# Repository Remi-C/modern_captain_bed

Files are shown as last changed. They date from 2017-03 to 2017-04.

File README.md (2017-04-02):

# Modern captain bed #

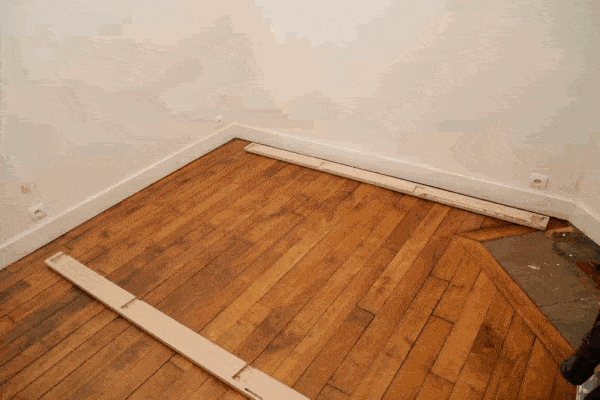
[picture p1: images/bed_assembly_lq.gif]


## Presentation ##

This is a re-design of captain bed in a modern fashion.

The main design ideas :
 - a nice wooden bed inspired by nautical captain bed
 - massive amount of storage (about 2 m3!)
 - Massive wood, traditionnal joinery for strength and durability
 - fully dismountable into small pieces (one person carry)
 - Can be build with reasonnably common tools/

warning : the original design documents are in french, I translated the essential parts

Here is a detailed presentation of this moder captain bed project.

[Introductory presentation to the modern captain bed project](./presentation/modern_captain_bed_overall_presentation.pdf) ([French version](./presentation/modern_captain_bed_overall_presentation_LQ_fr.pdf))

## 3D model
A conceptual 3D model, simplified (no joinery, no handles, simplified textures, etc.)

**click on 3D model to change view**
<div class="sketchfab-embed-wrapper"><iframe width="800" height="600" src="https://sketchfab.com/models/c7bc11224e4042eab323be94998c2b65/embed" frameborder="0" allowvr allowfullscreen mozallowfullscreen="true" webkitallowfullscreen="true" onmousewheel=""></iframe>

<p style="font-size: 13px; font-weight: normal; margin: 5px; color: #4A4A4A;">
    <a href="https://sketchfab.com/models/c7bc11224e4042eab323be94998c2b65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" target="_blank" style="font-weight: bold; color: #1CAAD9;">Modern Captain Bed</a>
    by <a href="https://sketchfab.com/RCura?utm_medium=embed&utm_source=website&utm_campain=share-popup" target="_blank" style="font-weight: bold; color: #1CAAD9;">RCura</a>
    on <a href="https://sketchfab.com?utm_medium=embed&utm_source=website&utm_campain=share-popup" target="_blank" style="font-weight: bold; color: #1CAAD9;">Sketchfab</a>
</p>
</div>
 
[Go to `3D_model` for 3D model !](./3D_model/modern_captain_bed.dae)

## Design
The design took several months as the project is mechanically complex to solve with traditionnal joinery wihtout loosing storage space.
Moreover, the dissassembled bed has to be easy to move and store.

**Clik on image to see other images**
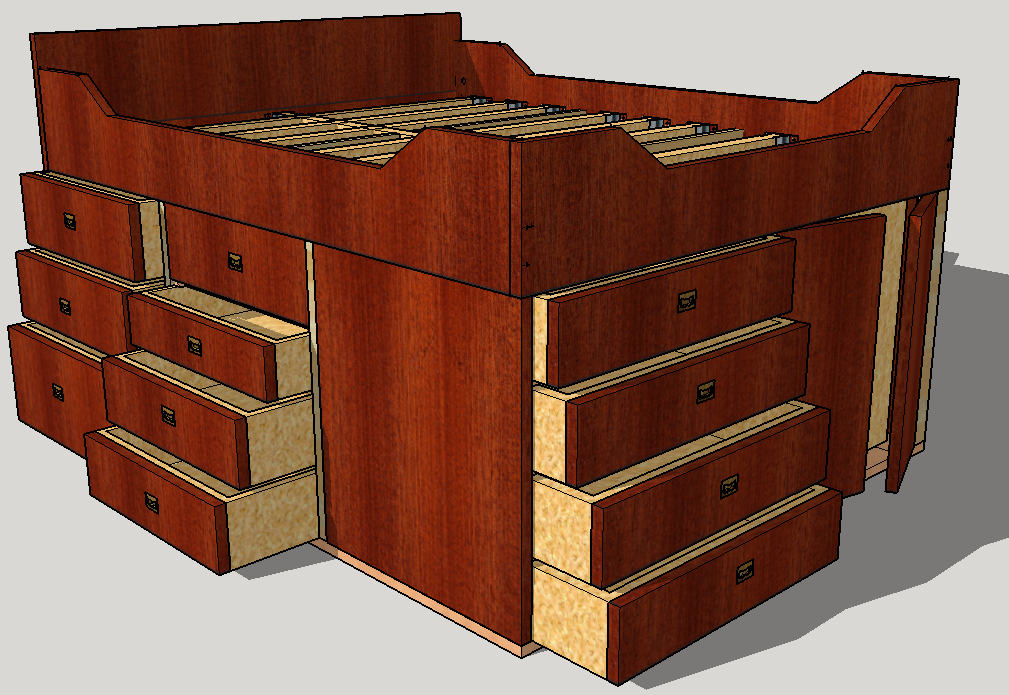
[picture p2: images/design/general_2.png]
Disassembled bed

The gallery of pictures for design contains many pictures about the design step.

The most recent version of the project design dimension are :

**Clik on image to see other images**
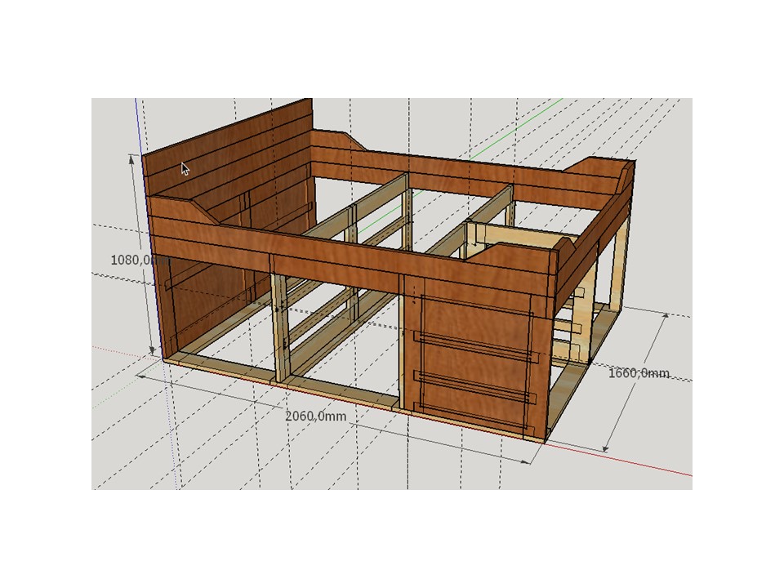
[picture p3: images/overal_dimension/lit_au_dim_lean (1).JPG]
overal dimension


## Building
The project was built in 6 months using evenings and week ends.
Overall, the project can be completed with common woodworking tools.
Mixing power tool and hand tool is also possible.

**clik on image to see other images**
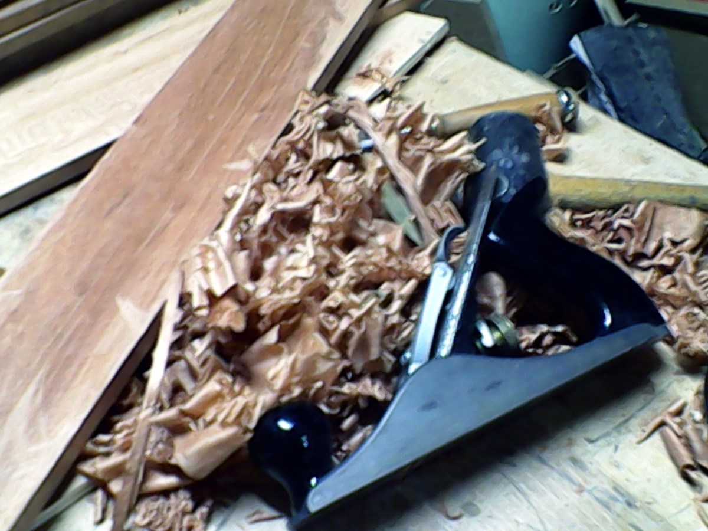
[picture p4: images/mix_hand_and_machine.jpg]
hand tool
 
The gallery contains some pictures of the build process.

### build-book
Beside the 3D model, the [build book](./building/build_book/modern_captain_bed_build_book.pdf) contains illustrated parts, nomenclature and measurements.

**clik on image to see other images**
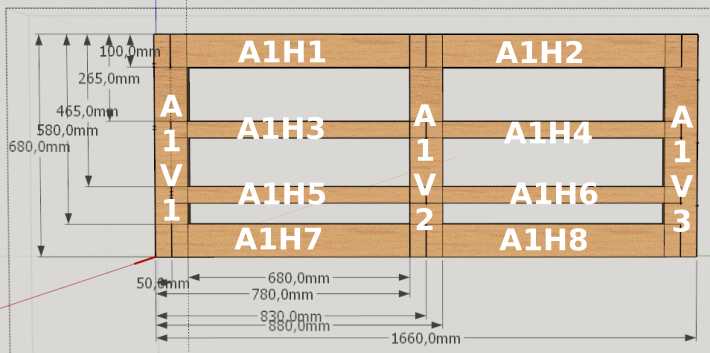
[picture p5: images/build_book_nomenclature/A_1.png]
gallery
.

### template
Some joins are duplicated heavily, which make them lenghty to draw on wood.
We propose numerical templates to be used with router or  similar tools.
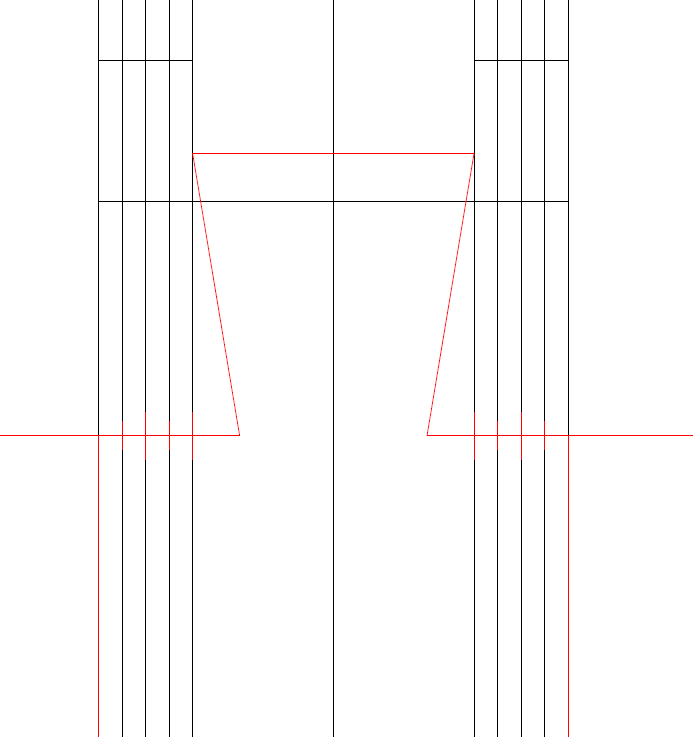
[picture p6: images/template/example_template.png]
numerical templates


## Assembly##
The main design advantage of this bed is the traditionnal joinery that allows full assembly / disassembly.
### Pictures of assembly
As shown in the assembly galleries, assembling bed is straightforward.

**clik on image to see other images**
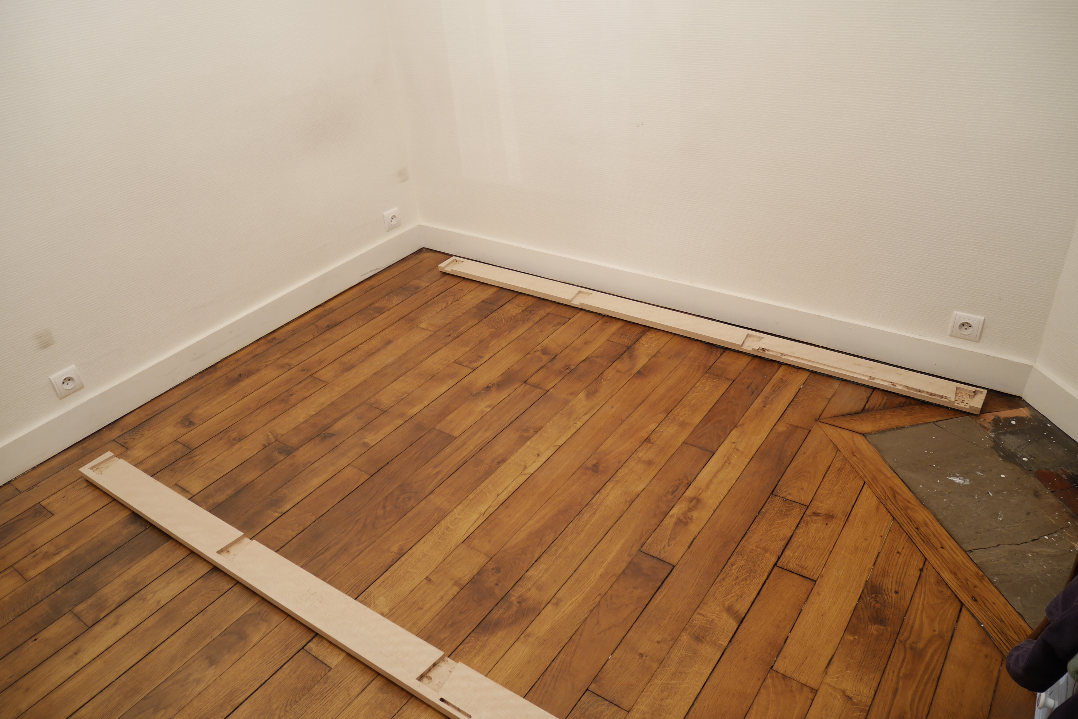
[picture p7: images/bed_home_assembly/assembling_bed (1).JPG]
assembling bed at home


**clik on image to see other images**
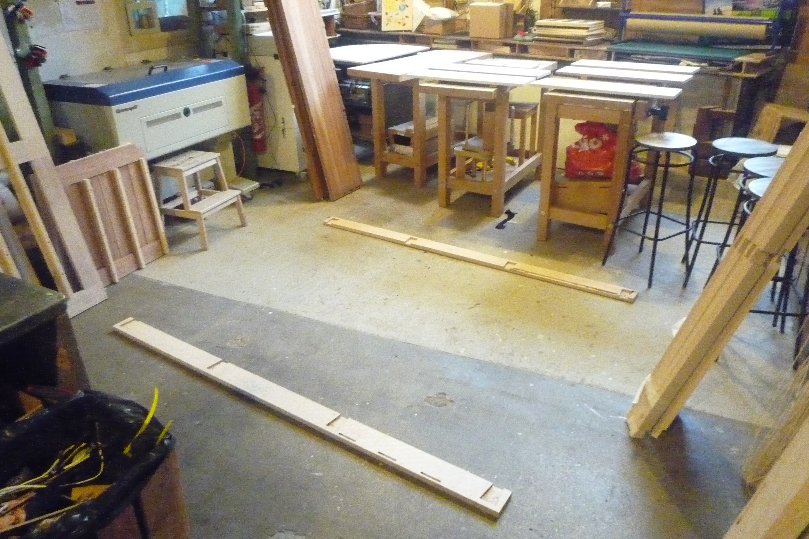
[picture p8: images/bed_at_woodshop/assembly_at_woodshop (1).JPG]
assembling bed at woodshop


### Moving the bed
The bed can be dissassembled into small parts, such that no part is longuer than 2 meters, larger than 40 cm, and of more than 10 cm of thickness.
Furthermore, each part is light enough to be carreid  by one person.
Overall, the bed dissassembled easily fit into a 2m x 1m x 0.3 m space. 
**clik on image to see other images**
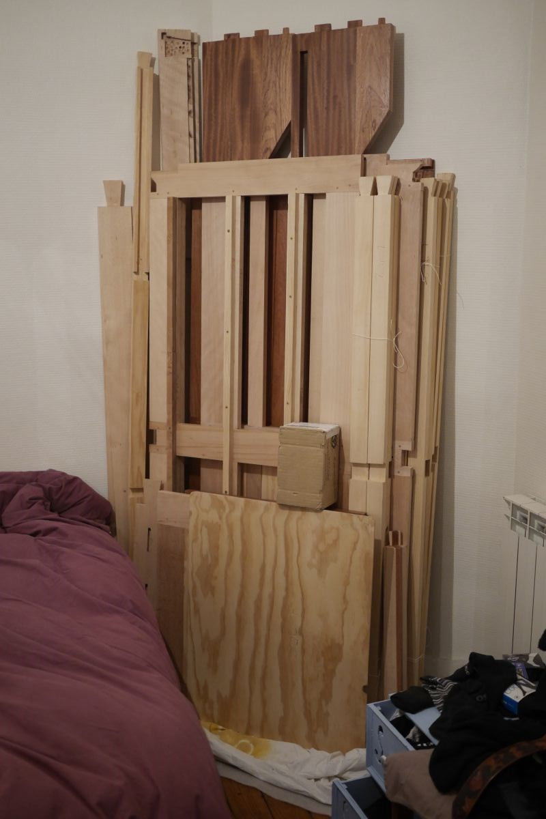
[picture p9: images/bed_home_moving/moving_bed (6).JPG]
Moving the bed


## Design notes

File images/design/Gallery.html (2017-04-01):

# Gallery

Click on picture to enlarge.





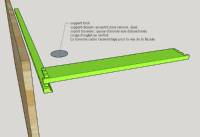
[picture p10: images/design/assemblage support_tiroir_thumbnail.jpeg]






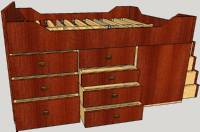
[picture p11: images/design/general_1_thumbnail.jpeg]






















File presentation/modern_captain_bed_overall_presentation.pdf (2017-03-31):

# A modern captain bed

# Rémi Cura, 2015

# Introduction

# - Main design ideas

# – A bed with massive storage space – Tough – Doable, can be assembled/disassembled – Beautifull materials for a nautic style esthetic

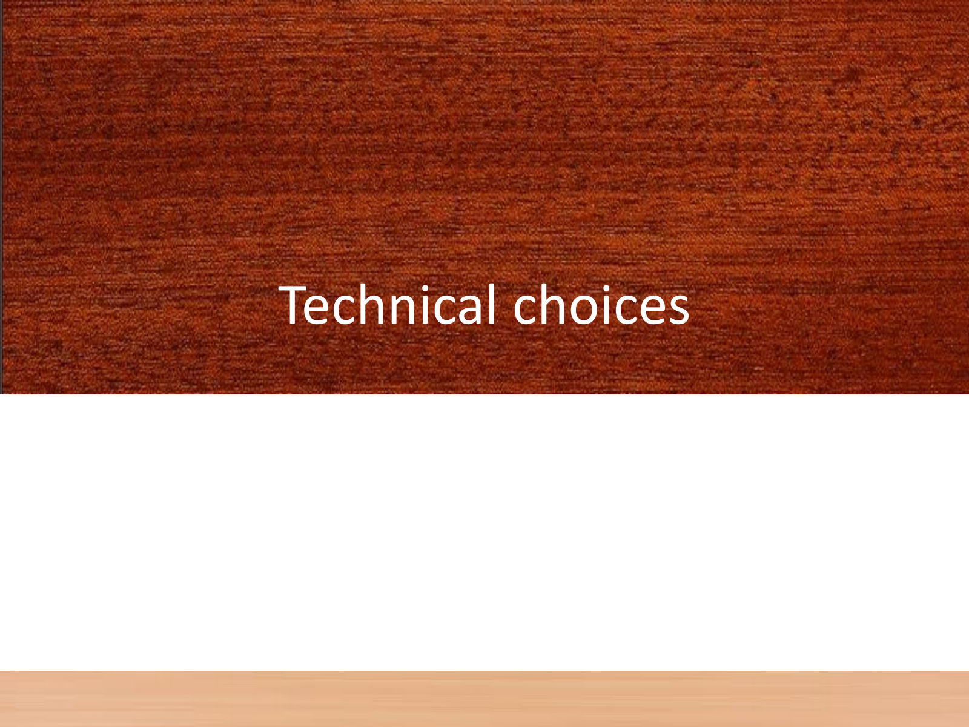
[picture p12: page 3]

# Technical choices

# Esthetic choices

# - Main inspiration is actual captain bed, in particular for:

## – Its compactness (nothing protruding) – Its warm colors (mahogany+ brass) – Its toughness – Its simplicity (no curves)

# - We adapt it to modern constraints

## – Maximal storing space – A few sharp edges accepted

# - Height

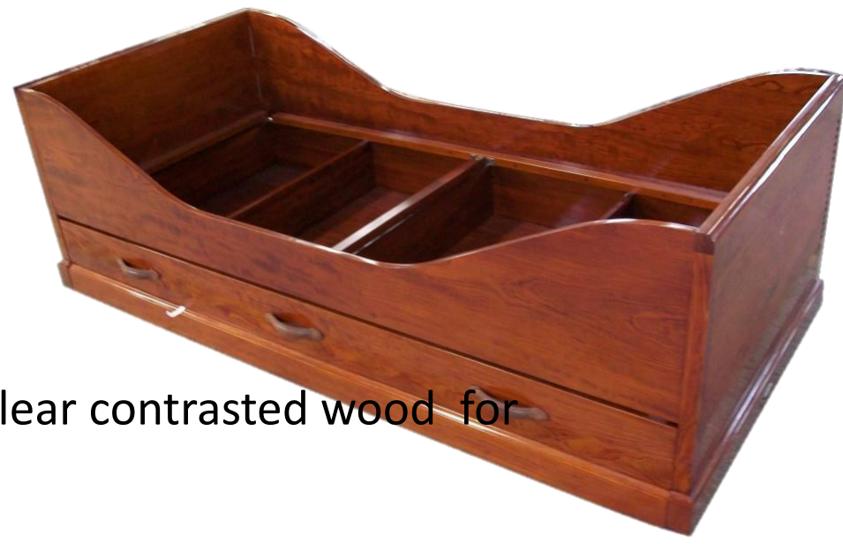
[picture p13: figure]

## – To limit the height impression, we use clear contrasted wood for vertical parts

# Technical choices

# - Passing through drawers (full bed width) - Main dimensions

## – Mattress is 1600*2000mm – Bed frame is at about height 850 mm – Thickness for main parts (belt) :30mm – Thickness structural part(frame) : 20 mm – Thickness secondary element (drawer bottom): 10mm

# - Joinery choices

## – removable – Mecanically sound – Easy to construct – Use metal parts only when absolutely necessary

# Technical choices

# - About materials

## – Visible wood:

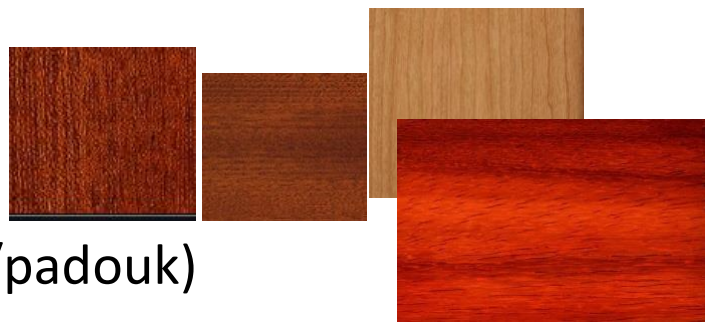
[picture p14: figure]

## - Hard, dark/red colour(acajou/sapelli/merisier/padouk)

## – Structure (cloison):

## - Hard, light colour: hêtre/chataignier/frêne

## – Drawer Not visible:

## - rigid cheap :plywood/latté

## – Mattress floor:

## - Light cheap(pin/epicea…)

# - hardware

## – Visible : brass – Invisible : brass/ stainless/ steel

# Technical choices

# - About sketchup 3D model

# – More a detailed concept – Joinery is sometime showed, but not always ( sketchup is buggy) – Some stuff are hand placed and are not precise

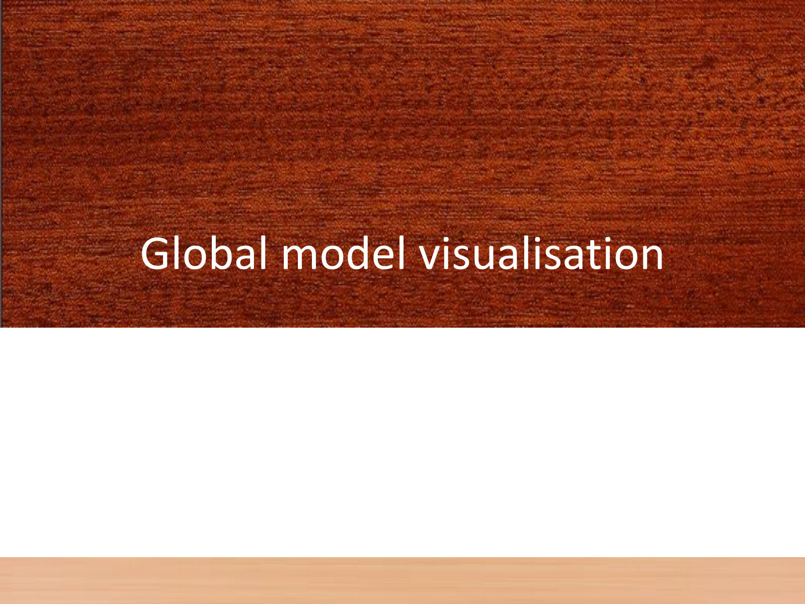
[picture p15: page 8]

# Global model visualisation

# Global visu

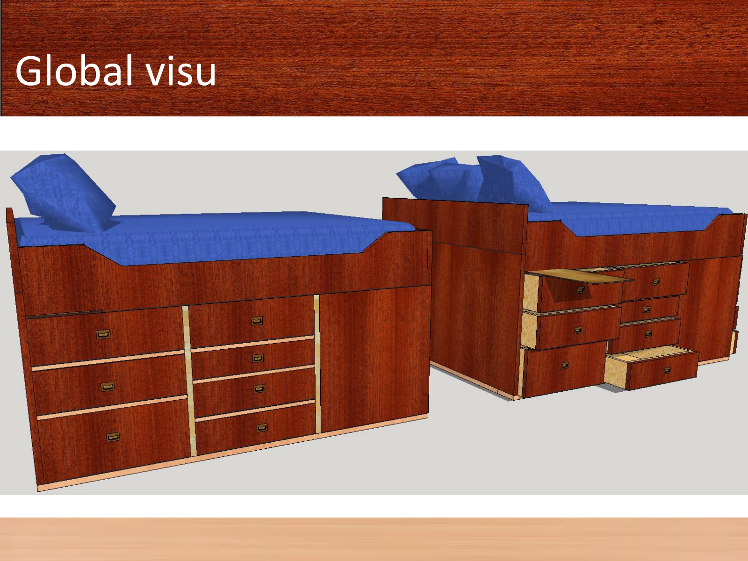
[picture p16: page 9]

# Global visu

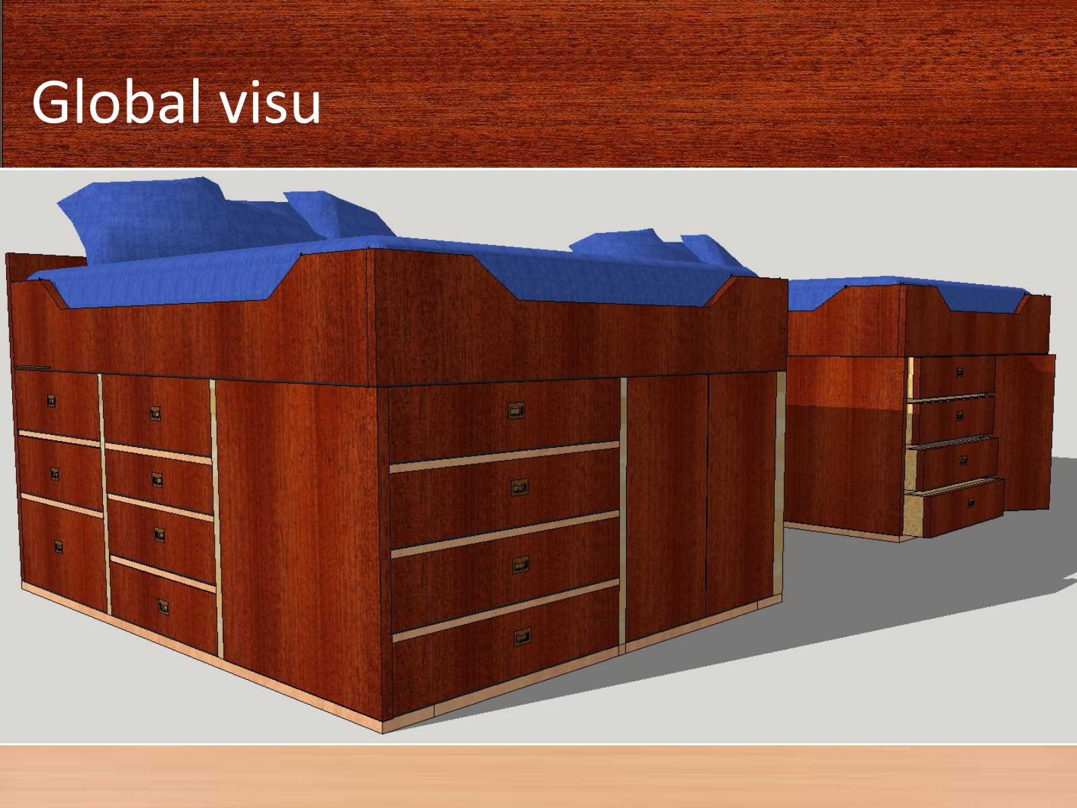
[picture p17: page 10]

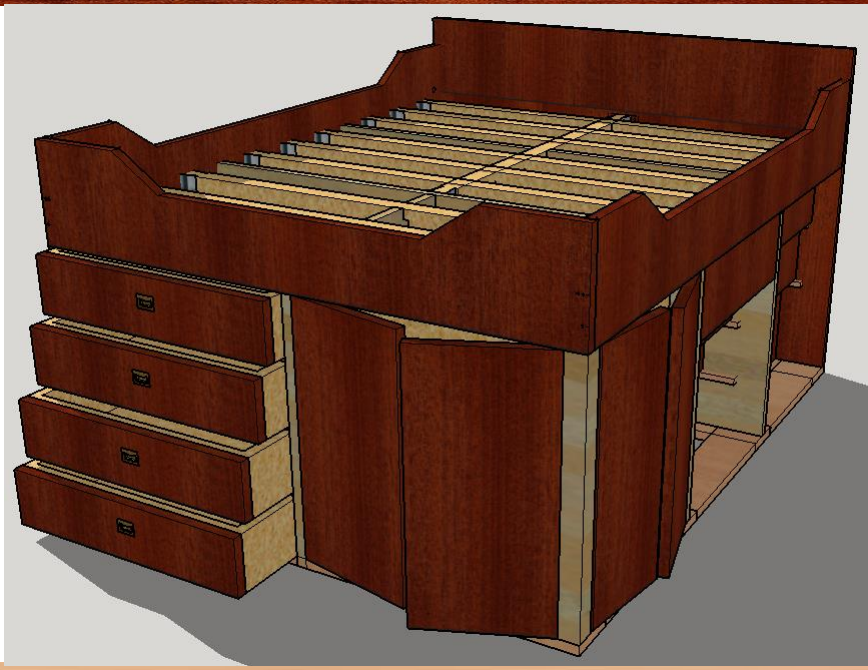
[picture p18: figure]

(all drawers and doors have handle)
(behing door, either a box, shelf, or nothing)

# Global visu

(all drawers and doors have handle)
(this illustration misses some

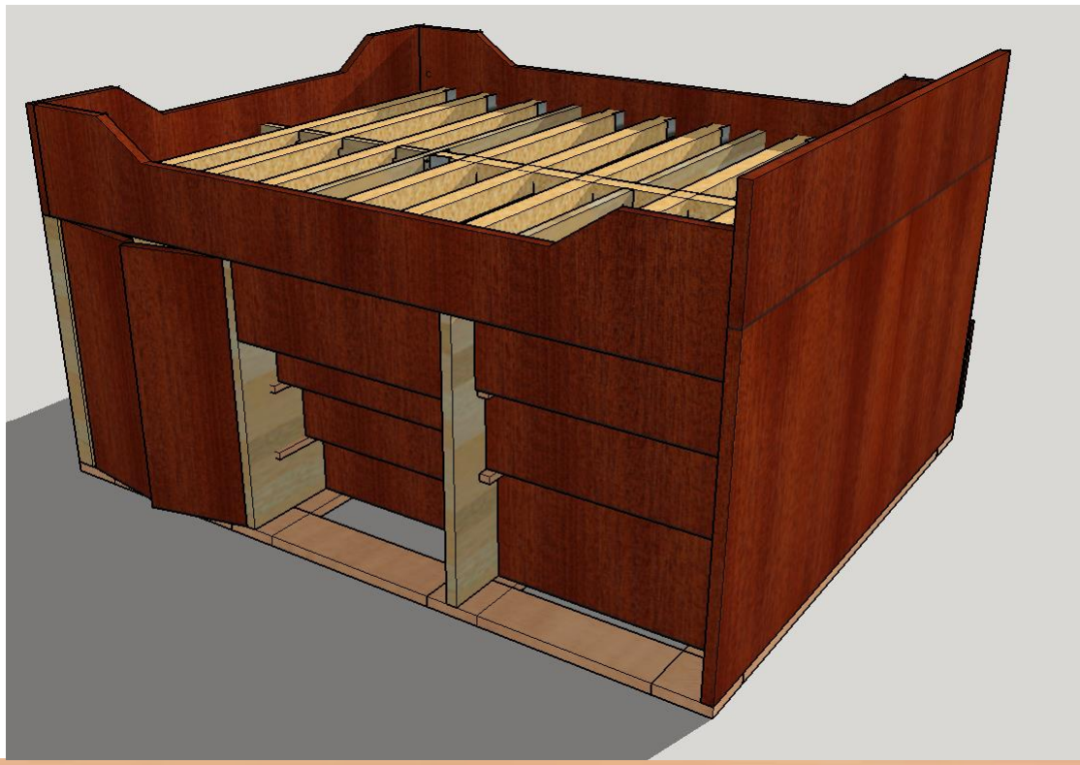
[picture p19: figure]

part of the drawers supports)

# Global visu

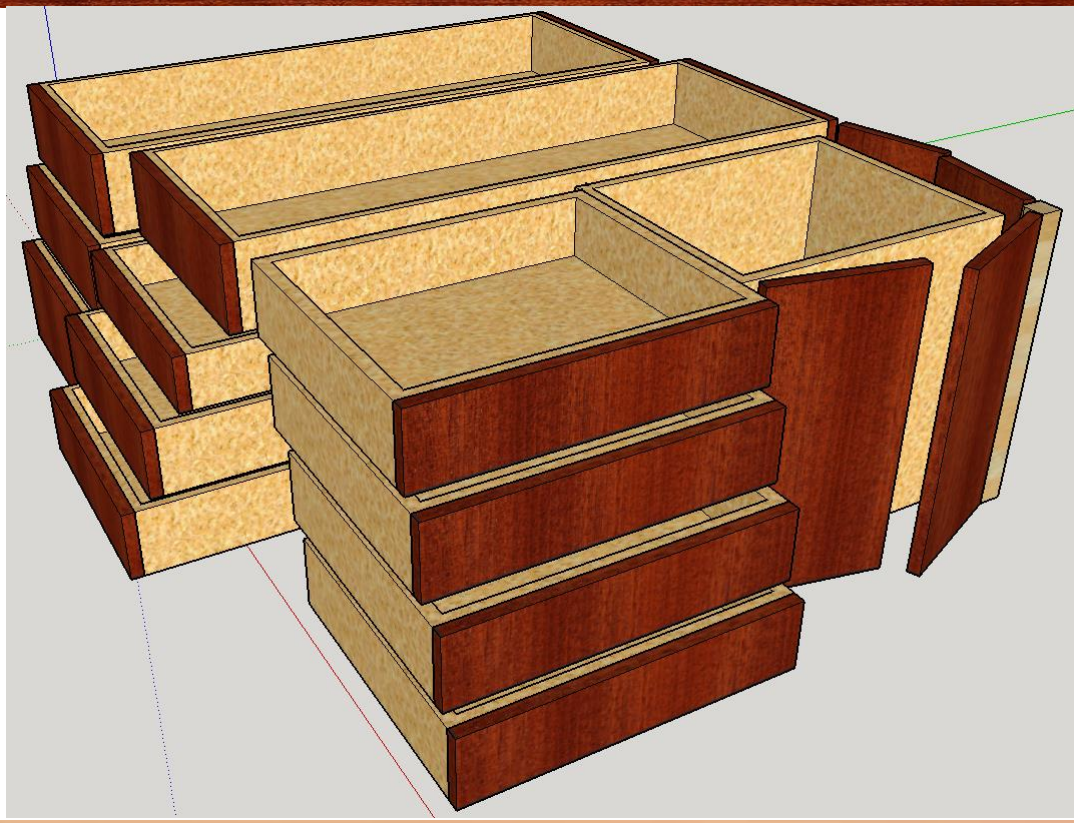
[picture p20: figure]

(tous les tiroirs et portes devraient avoir une poignée) (les assemblages des tiroirs ne sont pas montrés ici)

Note : les doubles portes
battantes permettent
d’accéder au même coffre.
Avec les tiroirs traversant, cela permet d’utiliser le
stockage même quand le lit est le long d’un murs sur un des côtés.
Les doubles battants
permettent un espace au
pied du lit plus réduit, et sont meilleurs d’un point de vue macanique (800mm de
portée un peu long pour un simple battant)

# Global visu

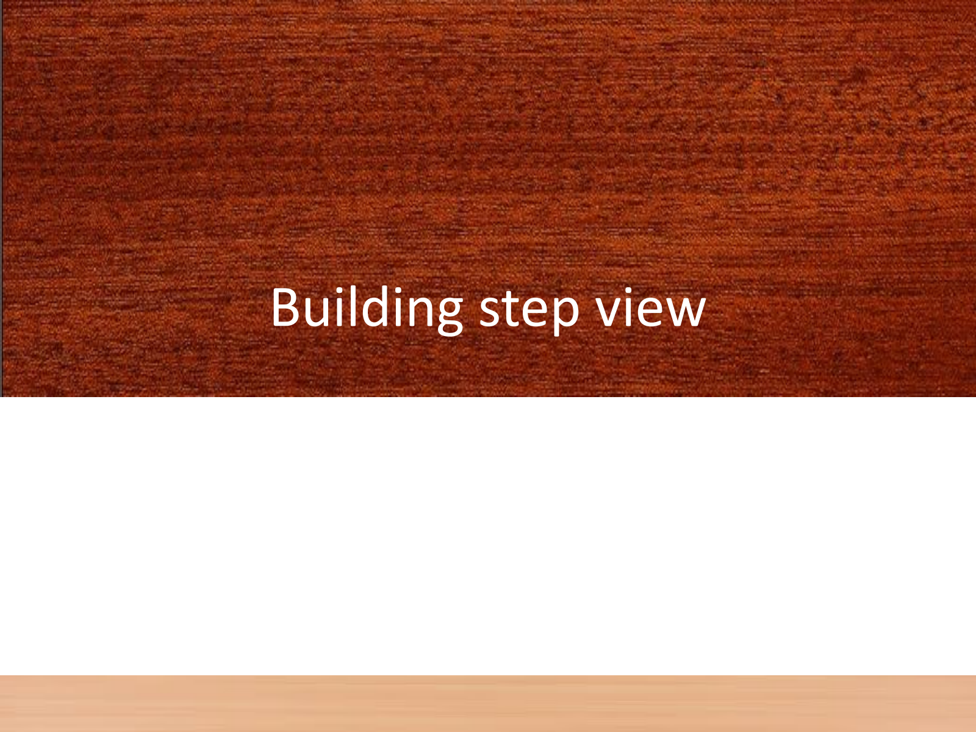
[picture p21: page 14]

# Building step view

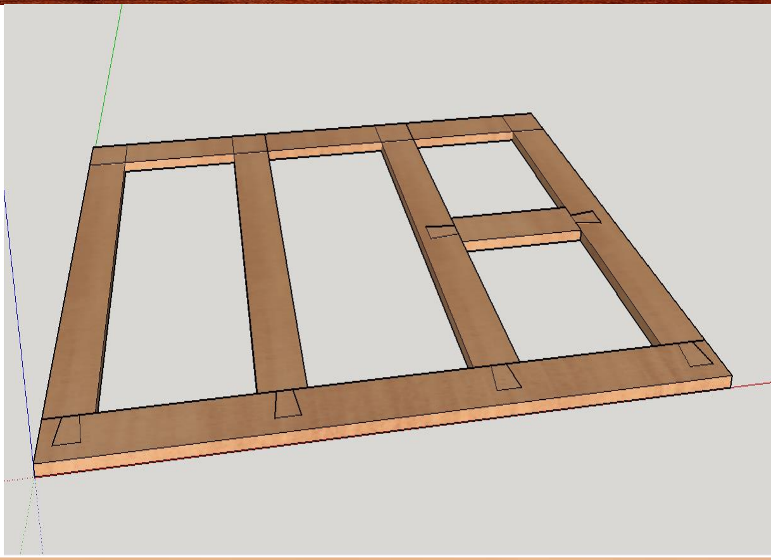
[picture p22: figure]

(Not all joins are drawn)

# Socle

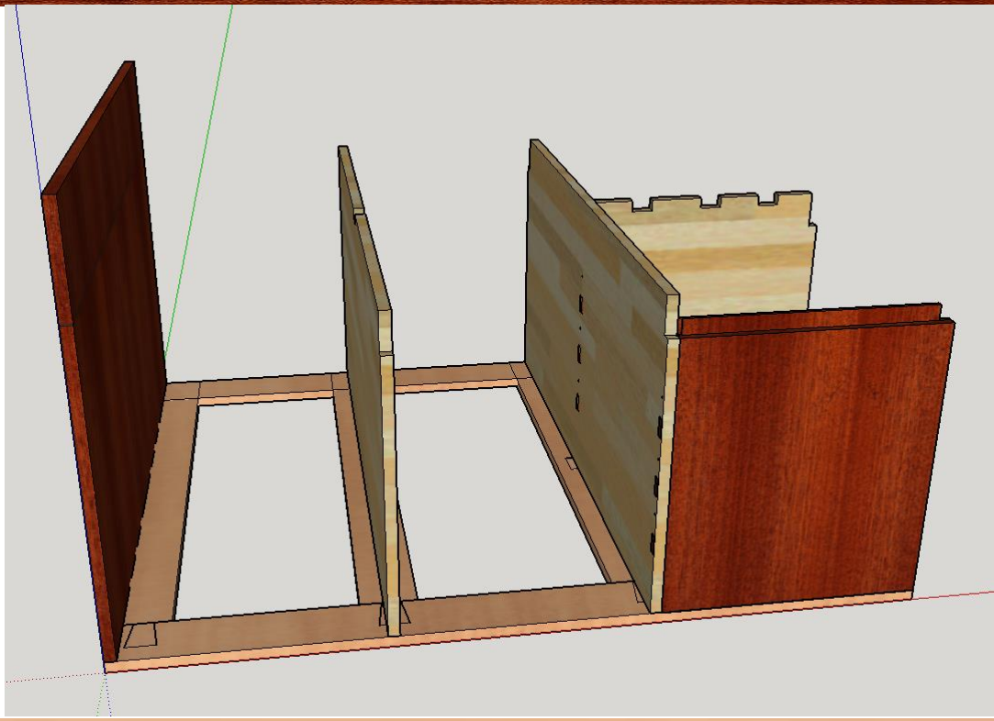
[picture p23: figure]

(Not all joins are drawn)

# + cloisons

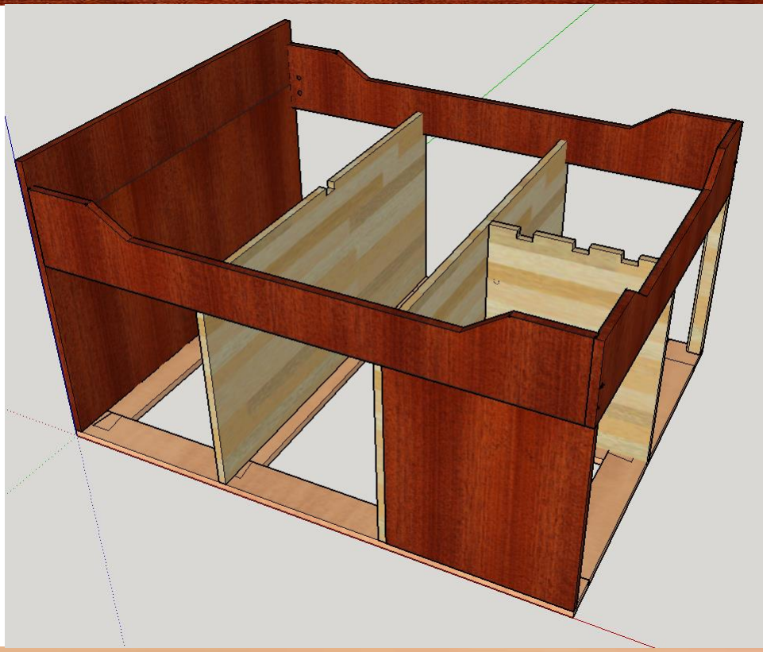
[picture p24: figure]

(Not all joins are drawn)

# + traverses

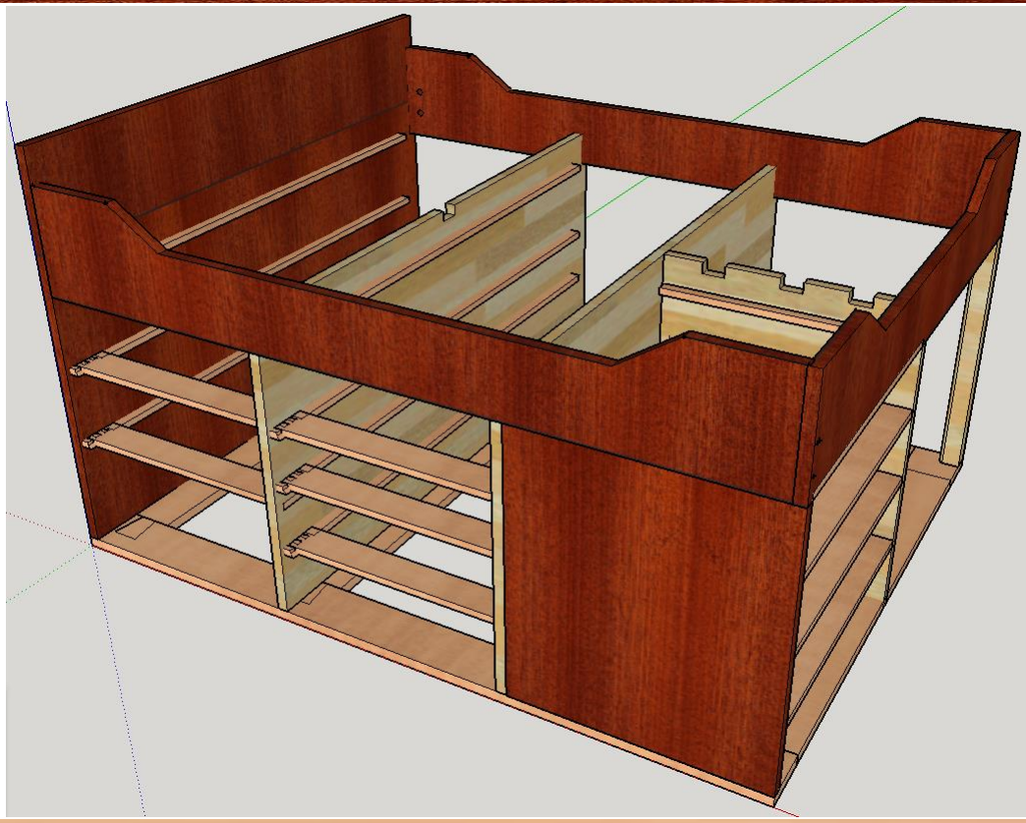
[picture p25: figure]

(Not all joins are drawn)

# + supports tiroirs

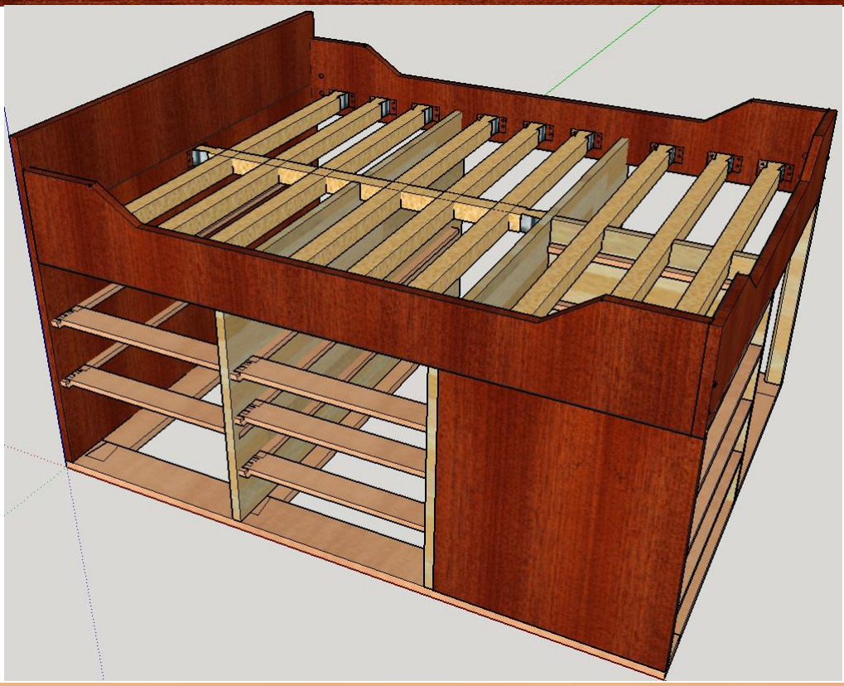
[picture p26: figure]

(Not all joins are drawn)

# + sommier

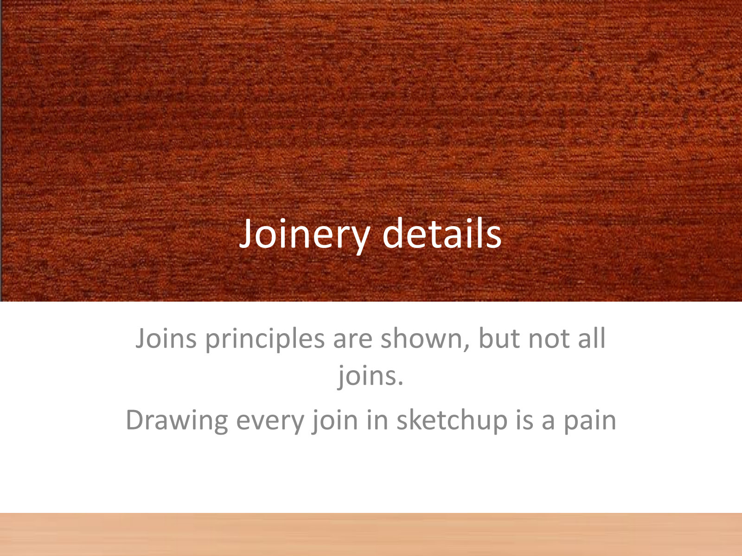
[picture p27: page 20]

# Joinery details

# Joins principles are shown, but not all

joins.

# Drawing every join in sketchup is a pain

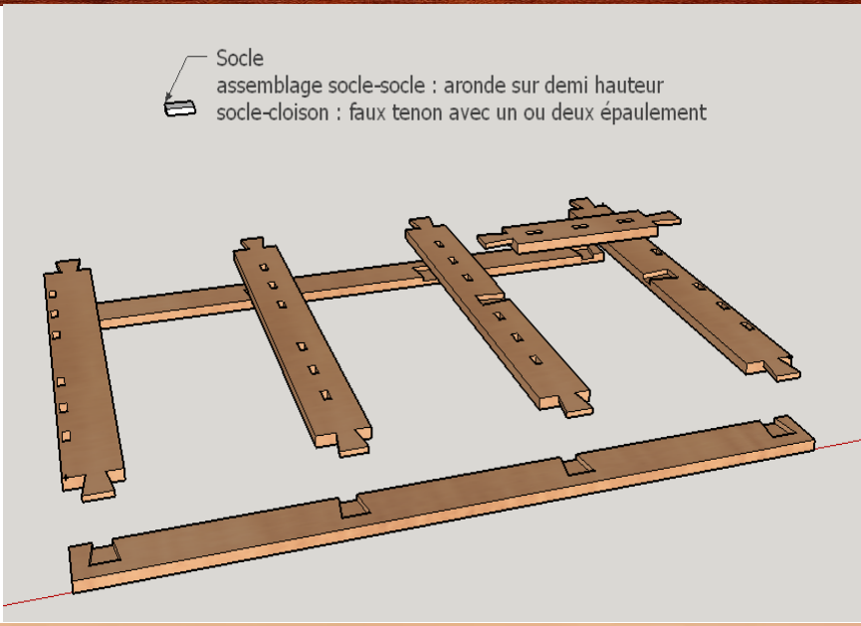
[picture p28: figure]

(Not all joins are drawn)
Dovetails on half width allow easy dissambly, are super
rigid, and will handle
dimension variations

Tenon are simple and save
wood

# + socle

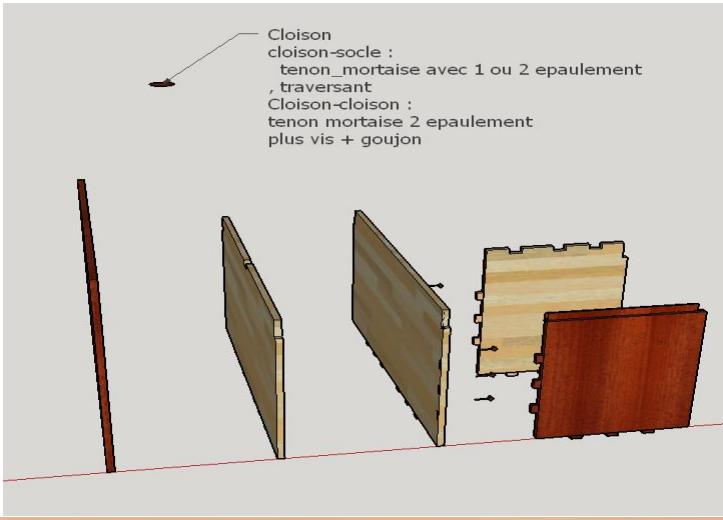
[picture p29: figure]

(Not all joins are drawn)
We use hardware to join
panneaux. This allow to
control tightness and is still easily removable.

# + cloisons

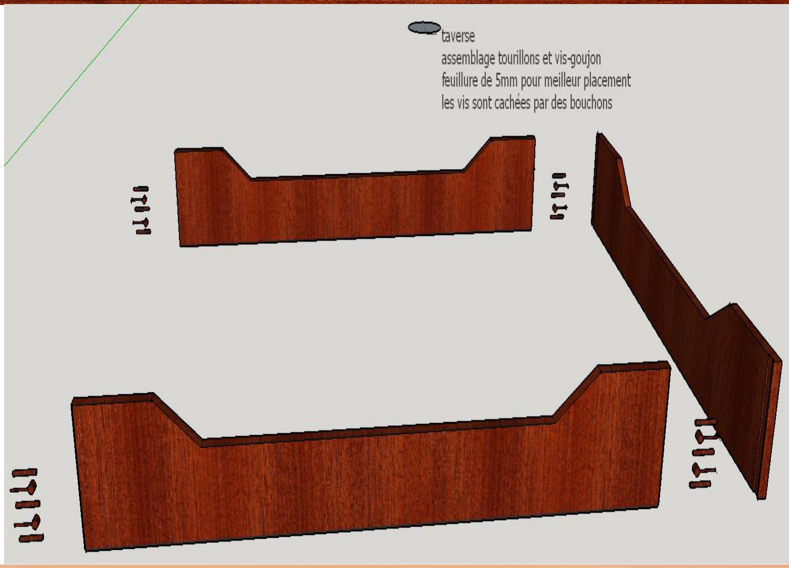
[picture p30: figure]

(Not all joins are drawn)

Il ne seemble pas y avoir bcp de possiblités pour ces
assemblages car la largeur des planches (30mm) est
insuffisante pour bcp
d’assemblages plus solides. Ces jonctions doivent être extremement fortes.
On utilise donc des vis
traversantes cachées par des bouchons de bois pour
l’esthétique

# + ceinture

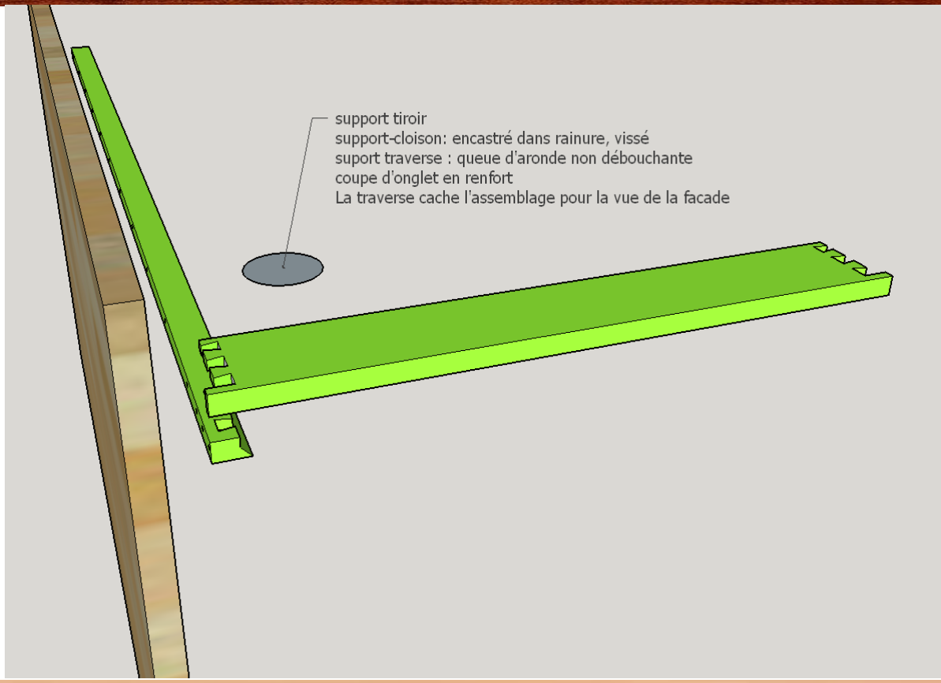
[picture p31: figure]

(tous les assemblages ne
sont pas représentés)

Ces assemblages devrait être faisable avec une défonceuse avec meche droite assez fine et gabarit.
C’est essentiel car il y en a bcp.
L’onglet en basde
l’assemblage permet de bien repartir la charge du tiroir Les arondes permettent de
transmettres les
mouvements des cloisons à
toute la structure

# + support tiroir

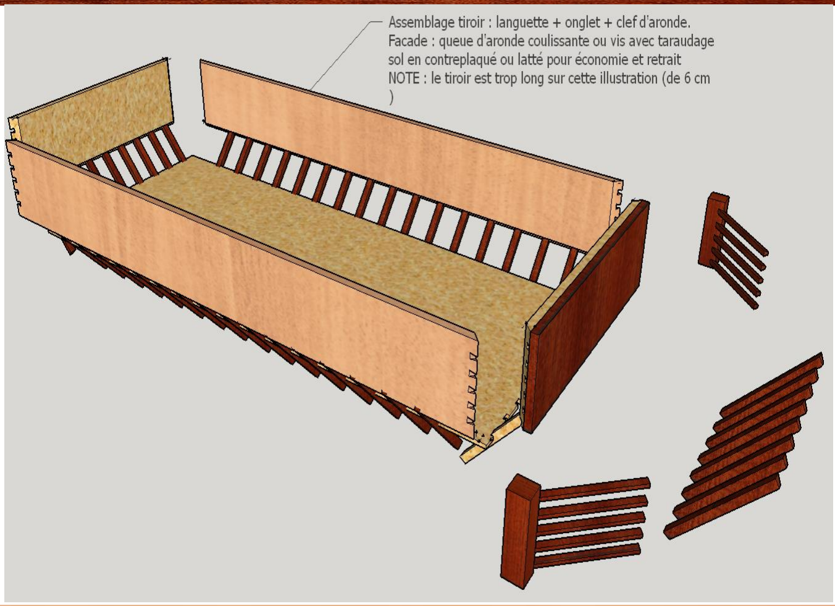
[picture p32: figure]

- Les clefs d’arondes sont représentées non coupées
- L’assemblage par clef
d’aronde semble etre un
bon compromis d’usinage,
puisqu’on fait d’abord un
assemblage « facile» avec
feuillures, puis on colle le tiroir.
- On défonce les clefs sur le tiroir déjà assemblé, ce qui évite l’utilisation d’un
gabarit à queue d’aronde.
- Mécaniquement les clefs
bloque traction et
déformation par le poids
- C’est esthétique si les clefs sont faites dans un autre
bois
- Elles ne sont pas
débouchantes sur la facade
- Le système de fixation
facade tiroir est soit vis taraudé, soit aronde
coulissante verticalement, ce qui ferait perdre bcp de bois

# + tiroir

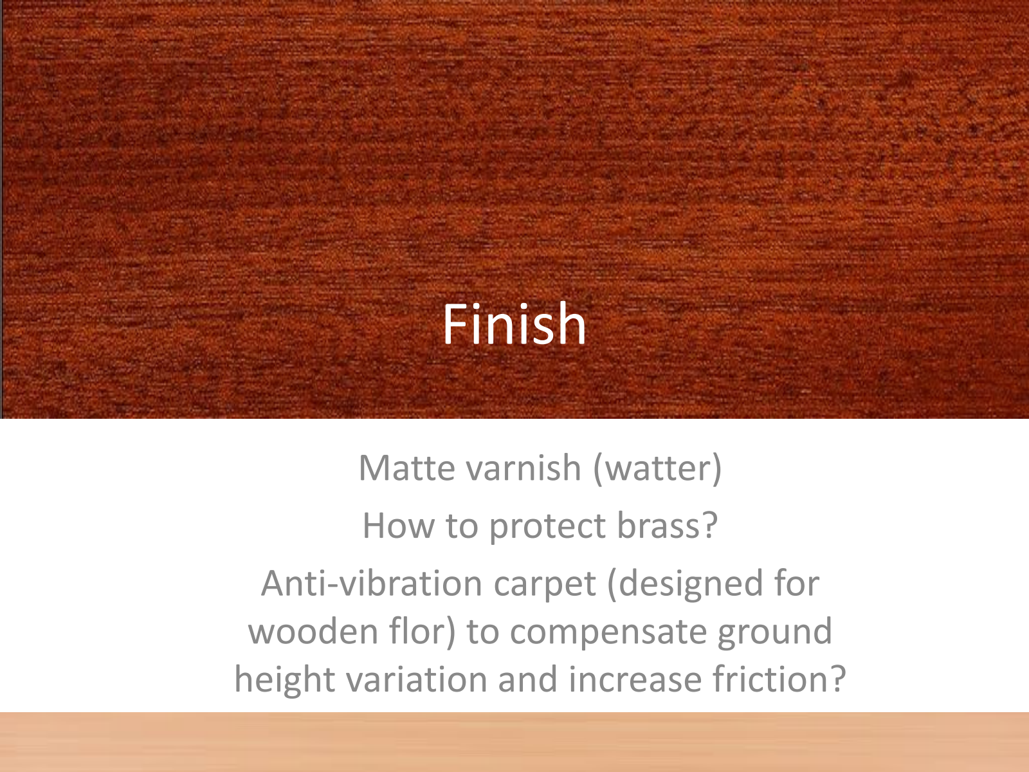
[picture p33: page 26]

# Finish

# Matte varnish (watter) How to protect brass? Anti-vibration carpet (designed for wooden flor) to compensate ground height variation and increase friction?


# Optionnal


Bonus:
A brass shelf.
Can be pushed inside
Can be used only fully in or fully out
Allow for a bedside table
without blocking drawers
opening
Joinery : groove; at the end, centering -45° + 45° profile.

Shelf surface is itched with acid, sculpted, or machined with cnc. Could also be
sculpted leather.
Idea for patter : nautical map from 19th century, vintage moon map.

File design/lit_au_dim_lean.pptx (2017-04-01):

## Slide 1


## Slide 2


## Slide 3





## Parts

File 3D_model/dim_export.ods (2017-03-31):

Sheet: Feuille1_3
Components
Part # | Sub-Assembly | Description | Length(L) | Width(W) | Thickness(T) | Cubic m | Material
C-001-01 | SOC | SOC_GD_2 | 1660,0mm | 100,0mm | 24,0mm | 0 | massif_hetre
C-002-01 | SOC | SOC_GD_4 | 1660,0mm | 100,0mm | 24,0mm | 0 | massif_hetre
C-003-01 | SOC | SOC_TP_1 | 2060,0mm | 100,0mm | 24,0mm | 0 | massif_hetre
C-004-01 | SOC | SOC_GD_3 | 1660,0mm | 100,0mm | 24,0mm | 0 | massif_hetre
C-005-01 | SOC | SOC_P | 710,0mm | 580,0mm | 10,0mm | 0 | contreplaquÃ©_pin
C-006-01 | SOC | SOC_TP_3 | 2060,0mm | 100,0mm | 24,0mm | 0 | massif_hetre
C-007-01 | SOC | SOC_TP_2 | 750,0mm | 100,0mm | 24,0mm | 0 | massif_hetre
C-008-01 | SOC | SOC_GD_1 | 1660,0mm | 100,0mm | 24,0mm | 0 | massif_hetre
C-009-01 | L_T | L_T_4 | 1600,0mm | 50,0mm | 30,0mm | 0 | tasseau_pin
C-010-01 | L_T | L_T_3 | 1600,0mm | 50,0mm | 30,0mm | 0 | tasseau_pin
C-011-01 | L_T | L_T_2 | 1600,0mm | 50,0mm | 30,0mm | 0 | tasseau_pin
C-012-01 | L_T | L_T_1 | 1600,0mm | 50,0mm | 30,0mm | 0 | tasseau_pin
C-013-01 | L_M | L_M_4 | 1600,0mm | 50,0mm | 30,0mm | 0 | tasseau_pin
C-014-01 | L_M | L_M_3 | 1600,0mm | 50,0mm | 30,0mm | 0 | tasseau_pin
C-015-01 | L_M | L_M_2 | 1600,0mm | 50,0mm | 30,0mm | 0 | tasseau_pin
C-016-01 | L_M | L_M_1 | 1600,0mm | 50,0mm | 30,0mm | 0 | tasseau_pin
C-017-01 | L_P | L_P_4 | 1600,0mm | 50,0mm | 30,0mm | 0 | tasseau_pin
C-018-01 | L_P | L_P_3 | 1600,0mm | 50,0mm | 30,0mm | 0 | tasseau_pin
C-019-01 | L_P | L_P_2 | 1600,0mm | 50,0mm | 30,0mm | 0 | tasseau_pin
C-020-01 | L_P | L_P_1 | 1600,0mm | 50,0mm | 30,0mm | 0 | tasseau_pin
C-021-01 | LS | LS_D | 2006,0mm | 50,0mm | 50,0mm | 0,01 | tasseau_pin
C-022-01 | LS | LS_T | 100,0mm | 50,0mm | 50,0mm | 0 | tasseau_pin
C-023-01 | LS | LS_G | 2006,0mm | 50,0mm | 50,0mm | 0,01 | tasseau_pin
C-024-01 | LS | LS_M | 2006,0mm | 50,0mm | 50,0mm | 0,01 | tasseau_pin
C-025-01 | LS | LS_P | 100,0mm | 50,0mm | 50,0mm | 0 | tasseau_pin
C-026-01 | ST_P_1 | ST_P_1_I_2 | 688,0mm | 24,0mm | 20,0mm | 0 | tasseau_pin
C-027-01 | ST_P_1 | ST_P_1_I_1 | 688,0mm | 24,0mm | 20,0mm | 0 | tasseau_pin
C-028-01 | ST_P_1 | ST_P_1_F_1 | 794,0mm | 100,0mm | 20,0mm | 0 | massif_hetre
C-029-01 | ST_P_2 | ST_P_2_I_1 | 688,0mm | 24,0mm | 20,0mm | 0 | tasseau_pin
C-030-01 | ST_P_2 | ST_P_2_I_2 | 688,0mm | 24,0mm | 20,0mm | 0 | tasseau_pin
C-031-01 | ST_P_2 | ST_P_2_F_1 | 794,0mm | 100,0mm | 20,0mm | 0 | massif_hetre
C-032-01 | ST_M_1 | ST_M_1_F_2 | 650,0mm | 100,0mm | 20,0mm | 0 | massif_hetre
C-033-01 | ST_M_1 | ST_M_1_I_1 | 1660,0mm | 24,0mm | 20,0mm | 0 | tasseau_pin
C-034-01 | ST_M_1 | ST_M_1_F_1 | 650,0mm | 100,0mm | 20,0mm | 0 | massif_hetre
C-035-01 | ST_M_1 | ST_M_1_I_2 | 1660,0mm | 24,0mm | 20,0mm | 0 | tasseau_pin
C-036-01 | ST_M_2 | ST_M_2_F_2 | 650,0mm | 100,0mm | 20,0mm | 0 | massif_hetre
C-037-01 | ST_M_2 | ST_M_2_I_2 | 1660,0mm | 24,0mm | 20,0mm | 0 | tasseau_pin
C-038-01 | ST_M_2 | ST_M_2_I_1 | 1660,0mm | 24,0mm | 20,0mm | 0 | tasseau_pin
C-039-01 | ST_M_2 | ST_M_2_F_1 | 650,0mm | 100,0mm | 20,0mm | 0 | massif_hetre
C-040-01 | ST_T | ST_T_F_2 | 650,0mm | 100,0mm | 20,0mm | 0 | massif_hetre
C-041-01 | ST_T | ST_T_F_1 | 650,0mm | 100,0mm | 20,0mm | 0 | massif_hetre
C-042-01 | ST_T | ST_T_I_2 | 1660,0mm | 24,0mm | 20,0mm | 0 | tasseau_pin
C-043-01 | ST_T | ST_T_I_1 | 1660,0mm | 24,0mm | 20,0mm | 0 | tasseau_pin
C-044-01 | C_T | C_T_1 | 1660,0mm | 100,0mm | 24,0mm | 0 | massif_sipo
C-045-01 | C_T | C_T_2 | 1660,0mm | 100,0mm | 24,0mm | 0 | massif_sipo
C-046-01 | C_T | C_T_3 | 1660,0mm | 100,0mm | 24,0mm | 0 | massif_sipo
C-047-01 | C_T | C_T_4 | 1660,0mm | 100,0mm | 24,0mm | 0 | massif_sipo
C-048-01 | C_D | C_D_1 | 2060,0mm | 100,0mm | 30,0mm | 0,01 | massif_sipo
C-049-01 | C_D | C_D_2 | 2060,0mm | 100,0mm | 30,0mm | 0,01 | massif_sipo
C-050-01 | C_D | C_D_3_P | 410,0mm | 100,0mm | 30,0mm | 0 | massif_sipo
C-051-01 | C_D | C_D_3_T | 410,0mm | 100,0mm | 30,0mm | 0 | massif_sipo
C-052-01 | C_G | C_G_1 | 2060,0mm | 100,0mm | 30,0mm | 0,01 | massif_sipo
C-053-01 | C_G | C_G_2 | 2060,0mm | 100,0mm | 30,0mm | 0,01 | massif_sipo
C-054-01 | C_G | C_G_3_T | 410,0mm | 100,0mm | 30,0mm | 0 | massif_sipo
C-055-01 | C_G | C_G_3_P | 410,0mm | 100,0mm | 30,0mm | 0 | massif_sipo
C-056-01 | C_P | C_P_2 | 1660,0mm | 100,0mm | 30,0mm | 0 | massif_sipo
C-057-01 | C_P | C_P_4_D | 410,0mm | 100,0mm | 30,0mm | 0 | massif_sipo
C-058-01 | C_P | C_P_1 | 1660,0mm | 100,0mm | 30,0mm | 0 | massif_sipo
C-059-01 | C_P | C_P_4_G | 410,0mm | 100,0mm | 30,0mm | 0 | massif_sipo
C-060-01 | A_T_C | A_T_H_8 | 780,0mm | 100,0mm | 24,0mm | 0 | massif_sipo
C-061-01 | A_T_C | A_T_V_1 | 680,0mm | 100,0mm | 24,0mm | 0 | massif_sipo
C-062-01 | A_T_C | A_T_V_3 | 680,0mm | 100,0mm | 24,0mm | 0 | massif_sipo
C-063-01 | A_T_C | A_T_V_2 | 680,0mm | 100,0mm | 24,0mm | 0 | massif_sipo
C-064-01 | A_T_C | A_T_H_7 | 780,0mm | 100,0mm | 24,0mm | 0 | massif_sipo
C-065-01 | A_T_C | A_T_H_2 | 780,0mm | 100,0mm | 24,0mm | 0 | massif_sipo
C-066-01 | A_T_C | A_T_H_1 | 780,0mm | 100,0mm | 24,0mm | 0 | massif_sipo
C-067-01 | A_T_C | A_T_H_3 | 780,0mm | 50,0mm | 24,0mm | 0 | massif_sipo
C-068-01 | A_T_C | A_T_H_4 | 780,0mm | 50,0mm | 24,0mm | 0 | massif_sipo
C-069-01 | A_T_P | A_T_P_3_3 | 710,0mm | 95,0mm | 10,0mm | 0 | massif_sipo
C-070-01 | A_T_P | A_T_P_4_1 | 710,0mm | 110,0mm | 10,0mm | 0 | massif_sipo
C-071-01 | A_T_P | A_T_P_4_2 | 710,0mm | 110,0mm | 10,0mm | 0 | massif_sipo
C-072-01 | A_T_P | A_T_P_4_3 | 710,0mm | 95,0mm | 10,0mm | 0 | massif_sipo
C-073-01 | A_T_P | A_T_P_2_2 | 710,0mm | 95,0mm | 10,0mm | 0 | massif_sipo
C-074-01 | A_T_P | A_T_P_3_2 | 710,0mm | 110,0mm | 10,0mm | 0 | massif_sipo
C-075-01 | A_T_P | A_T_P_2_1 | 710,0mm | 110,0mm | 10,0mm | 0 | massif_sipo
C-076-01 | A_T_P | A_T_P_1_2 | 710,0mm | 95,0mm | 10,0mm | 0 | massif_sipo
C-077-01 | A_T_P | A_T_P_1_1 | 710,0mm | 110,0mm | 10,0mm | 0 | massif_sipo
C-078-01 | A_T_P | A_T_P_3_1 | 710,0mm | 110,0mm | 10,0mm | 0 | massif_sipo
C-079-01 | A_P_G_C | A_P_G_H_2 | 588,0mm | 50,0mm | 24,0mm | 0 | massif_sipo
C-080-01 | A_P_G_C | A_P_G_H_3 | 588,0mm | 50,0mm | 24,0mm | 0 | massif_sipo
C-081-01 | A_P_G_C | A_P_G_V_2 | 680,0mm | 100,0mm | 24,0mm | 0 | massif_sipo
C-082-01 | A_P_G_C | A_P_G_V_1 | 680,0mm | 100,0mm | 24,0mm | 0 | massif_sipo
C-083-01 | A_P_G_C | A_P_G_H_1 | 588,0mm | 100,0mm | 24,0mm | 0 | massif_sipo
C-084-01 | A_P_G_C | A_P_G_H_4 | 588,0mm | 100,0mm | 24,0mm | 0 | massif_sipo
C-085-01 | A_P_G_P | A_P_G_C_1_1 | 518,0mm | 110,0mm | 10,0mm | 0 | massif_sipo
C-086-01 | A_P_G_P | A_P_G_C_1_2 | 518,0mm | 95,0mm | 10,0mm | 0 | massif_sipo
C-087-01 | A_P_G_P | A_P_G_C_3 | 518,0mm | 95,0mm | 10,0mm | 0 | massif_sipo
C-088-01 | A_P_G_P | A_P_G_C_2_2 | 518,0mm | 90,0mm | 10,0mm | 0 | massif_sipo
C-089-01 | A_P_G_P | A_P_G_C_2_1 | 518,0mm | 100,0mm | 10,0mm | 0 | massif_sipo
C-090-01 | A_P_D_C | A_P_D_H_3 | 588,0mm | 50,0mm | 24,0mm | 0 | massif_hetre
C-091-01 | A_P_D_C | A_P_D_H_2 | 588,0mm | 50,0mm | 24,0mm | 0 | massif_hetre
C-092-01 | A_P_D_C | A_P_D_H_1 | 588,0mm | 100,0mm | 24,0mm | 0 | massif_hetre
C-093-01 | A_P_D_C | A_P_D_V_2 | 680,0mm | 100,0mm | 24,0mm | 0 | massif_hetre
C-094-01 | A_P_D_C | A_P_D_V_1 | 680,0mm | 100,0mm | 24,0mm | 0 | massif_hetre
C-095-01 | A_P_D_C | A_P_D_H_4 | 588,0mm | 100,0mm | 24,0mm | 0 | massif_hetre
C-096-01 | A_P_D_P | A_P_D_P_2 | 518,0mm | 180,0mm | 10,0mm | 0 | contreplaquÃ©_pin
C-097-01 | A_P_D_P | A_P_D_P_1 | 518,0mm | 195,0mm | 10,0mm | 0 | contreplaquÃ©_pin
C-098-01 | A_P_D_P | A_P_D_P_3 | 518,0mm | 95,0mm | 10,0mm | 0 | contreplaquÃ©_pin
C-099-01 | A_2_C | A_2_H_2 | 780,0mm | 100,0mm | 24,0mm | 0 | massif_hetre
C-100-01 | A_2_C | A_2_V_1 | 680,0mm | 100,0mm | 24,0mm | 0 | massif_hetre
C-101-01 | A_2_C | A_2_H_1 | 780,0mm | 100,0mm | 24,0mm | 0 | massif_hetre
C-102-01 | A_2_C | A_2_H_8 | 780,0mm | 100,0mm | 24,0mm | 0 | massif_hetre
C-103-01 | A_2_C | A_2_V_3 | 680,0mm | 100,0mm | 24,0mm | 0 | massif_hetre
C-104-01 | A_2_C | A_2_H_3 | 780,0mm | 50,0mm | 24,0mm | 0 | massif_hetre
C-105-01 | A_2_C | A_2_H_6 | 780,0mm | 50,0mm | 24,0mm | 0 | massif_hetre
C-106-01 | A_2_C | A_2_H_7 | 780,0mm | 100,0mm | 24,0mm | 0 | massif_hetre
C-107-01 | A_2_C | A_2_V_2 | 680,0mm | 100,0mm | 24,0mm | 0 | massif_hetre
C-108-01 | A_2_C | A_2_H_4 | 780,0mm | 50,0mm | 24,0mm | 0 | massif_hetre
C-109-01 | A_2_C | A_2_H_5 | 780,0mm | 50,0mm | 24,0mm | 0 | massif_hetre
C-110-01 | A_2_P | A_2_P_2 | 710,0mm | 180,0mm | 10,0mm | 0 | contreplaquÃ©_pin
C-111-01 | A_2_P | A_2_P_1 | 710,0mm | 195,0mm | 10,0mm | 0 | contreplaquÃ©_pin
C-112-01 | A_2_P | A_2_P_3 | 710,0mm | 95,0mm | 10,0mm | 0 | contreplaquÃ©_pin
C-113-01 | A_1 | A_1_H_2 | 780,0mm | 100,0mm | 24,0mm | 0 | massif_hetre
C-114-01 | A_1 | A_1_V_1 | 680,0mm | 100,0mm | 24,0mm | 0 | massif_hetre
C-115-01 | A_1 | A_1_H_8 | 780,0mm | 100,0mm | 24,0mm | 0 | massif_hetre
C-116-01 | A_1 | A_1_H_6 | 780,0mm | 50,0mm | 24,0mm | 0 | massif_hetre
C-117-01 | A_1 | A_1_H_3 | 780,0mm | 50,0mm | 24,0mm | 0 | massif_hetre
C-118-01 | A_1 | A_1_H_5 | 780,0mm | 50,0mm | 24,0mm | 0 | massif_hetre
C-119-01 | A_1 | A_1_V_3 | 680,0mm | 100,0mm | 24,0mm | 0 | massif_hetre
C-120-01 | A_1 | A_1_H_7 | 780,0mm | 100,0mm | 24,0mm | 0 | massif_hetre
C-121-01 | A_1 | A_1_H_1 | 780,0mm | 100,0mm | 24,0mm | 0 | massif_hetre
C-122-01 | A_1 | A_1_H_4 | 780,0mm | 50,0mm | 24,0mm | 0 | massif_hetre
C-123-01 | A_1 | A_1_V_2 | 680,0mm | 100,0mm | 24,0mm | 0 | massif_hetre
C-124-01 | A_PI | A_PI_2_D | 704,0mm | 65,0mm | 20,0mm | 0 | massif_hetre
C-125-01 | A_PI | A_PI_3_D | 704,0mm | 25,0mm | 20,0mm | 0 | massif_hetre
C-126-01 | A_PI | A_PI_3_G | 704,0mm | 25,0mm | 20,0mm | 0 | massif_hetre
C-127-01 | A_PI | A_PI_2_G | 704,0mm | 65,0mm | 20,0mm | 0 | massif_hetre
C-128-01 | A_PI | A_PI_1 | 704,0mm | 85,0mm | 20,0mm | 0 | massif_sipo
Total Component Cubic m
0,23
Component Materials
Material | Cubic m
massif_hetre | 0,08
contreplaquÃ©_pin | 0,01
tasseau_pin | 0,05
massif_sipo | 0,09

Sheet: Feuille1
densité | min | max | vol | poids | prix /m3 | prix
sapelli | 0,6 | 0,75 | 0,11 | 74,86 | 1150 | 127,54
hetre | 0,8 | 0,9 | 0,08 | 72,17 | 760 | 64,52
pin | 0,4 | 0,5 | 0,0061 | 2,75

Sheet: Sheet1
Description | Quantité | Longueur mm | Largeur mm | Epaisseur mm | Total Length (m) | Material
support_tiroir | 4 | 680,6 | 24 | 20 | 2,72 | tasseau_pin
support_tiroir | 6 | 1660 | 24 | 20 | 9,96 | tasseau_pin
panneautage_pin | 1 | 518 | 180 | 10 | 0,52 | contreplaqué_pin
panneautage_pin | 1 | 710 | 180 | 10 | 0,71 | contreplaqué_pin
panneautage_pin | 1 | 518 | 195 | 10 | 0,52 | contreplaqué_pin
panneautage_pin | 1 | 710 | 195 | 10 | 0,71 | contreplaqué_pin
panneautage_pin | 1 | 710 | 580 | 10 | 0,71 | contreplaqué_pin
panneautage_pin | 1 | 518 | 95 | 10 | 0,52 | contreplaqué_pin
panneautage_pin | 1 | 710 | 95 | 10 | 0,71 | contreplaqué_pin
trait_facade_hetre | 2 | 650 | 20 | 10 | 1,3 | massif_hetre
pied_2 | 2 | 704 | 25 | 20 | 1,41 | massif_hetre
pied_1 | 2 | 704 | 64,9 | 20 | 1,41 | massif_hetre
suport_tiroir_visi | 6 | 650 | 100 | 20 | 3,9 | massif_hetre
suport_tiroir_visi | 2 | 794 | 100 | 20 | 1,59 | massif_hetre
cloison_cadre_hb | 6 | 680 | 100 | 24 | 4,08 | massif_hetre
cloison_inter_gd_b | 8 | 780 | 100 | 24 | 6,24 | massif_hetre
cloison_inter_gd_b#1 | 2 | 588 | 100 | 24 | 1,18 | massif_hetre
cloison_inter_hb_m | 2 | 680 | 100 | 24 | 1,36 | massif_hetre
socle_G | 2 | 2060 | 100 | 24 | 4,12 | massif_hetre
socle_h | 4 | 1660 | 100 | 24 | 6,64 | massif_hetre
socle_hb | 1 | 750 | 100 | 24 | 0,75 | massif_hetre
cloison_inter | 8 | 780 | 50 | 24 | 6,24 | massif_hetre
cloison_traverse_avt_arreire | 2 | 588 | 50 | 24 | 1,18 | massif_hetre
panneautage_lateral | 1 | 518 | 100 | 10 | 0,52 | massif_sipo
cloison_panneauté | 2 | 710 | 110 | 10 | 1,42 | massif_sipo
cloison_panneauté | 2 | 710 | 110 | 10 | 1,42 | massif_sipo
cloison_panneauté | 2 | 710 | 110 | 10 | 1,42 | massif_sipo
panneautage_lateral | 2 | 518 | 110 | 10 | 1,04 | massif_sipo
cloison_exterieur | 1 | 518 | 195 | 10 | 0,52 | massif_sipo
panneautage_lateral | 1 | 518 | 90 | 10 | 0,52 | massif_sipo
panneautage_lateral | 1 | 518 | 94,7 | 10 | 0,52 | massif_sipo
cloison_panneauté | 1 | 710 | 95 | 10 | 0,71 | massif_sipo
cloison_panneauté | 2 | 710 | 95 | 10 | 1,42 | massif_sipo
cloison_panneauté | 1 | 710 | 95 | 10 | 0,71 | massif_sipo
facade_tiroir | 24 | 650 | 95 | 10 | 15,6 | massif_sipo
pied_central_rotate | 1 | 704 | 84,9 | 20 | 0,7 | massif_sipo
cloison_cadre_hb#1 | 1 | 680 | 100 | 24 | 0,68 | massif_sipo
cloison_cadre_hb#2 | 1 | 680 | 100 | 24 | 0,68 | massif_sipo
cloison_inter_gd_b#2 | 2 | 588 | 100 | 24 | 1,18 | massif_sipo
tete_de_lit_24 | 4 | 1660 | 100 | 24 | 6,64 | massif_sipo
tete_de_lit_cadre | 4 | 780 | 100 | 24 | 3,12 | massif_sipo
tete_lit_cadre | 3 | 680 | 100 | 24 | 2,04 | massif_sipo
cloison_traverse_avt_arreire#1 | 1 | 588 | 50 | 24 | 0,59 | massif_sipo
cloison_traverse_avt_arreire#2 | 1 | 588 | 50 | 24 | 0,59 | massif_sipo
tete_de_lit_support | 2 | 780 | 50 | 24 | 1,56 | massif_sipo
traverse_avt_arreiere_stylisation | 4 | 407 | 100 | 30 | 1,63 | massif_sipo
traverse_avt_arreiere_stylisation#1 | 2 | 434,3 | 100 | 30 | 0,87 | massif_sipo
traverse_avt_arriere_long | 6 | 2060 | 100 | 30 | 12,36 | massif_sipo

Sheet: Sheet2
 | Sub-Assembly | Description | Length(L) | Width(W) | Thickness(T) | Cubic m | Material
 | LS | LS_D | 2006,0mm | 50,0mm | 50,0mm | 0,01 | tasseau_pin
 | LS | LS_G | 2006,0mm | 50,0mm | 50,0mm | 0,01 | tasseau_pin
 | LS | LS_M | 2006,0mm | 50,0mm | 50,0mm | 0,01 | tasseau_pin
 | LS | LS_T | 100,0mm | 50,0mm | 50,0mm | 0 | tasseau_pin
 | LS | LS_P | 100,0mm | 50,0mm | 50,0mm | 0 | tasseau_pin
 | L_T | L_T_4 | 1600,0mm | 50,0mm | 30,0mm | 0 | tasseau_pin
 | L_T | L_T_3 | 1600,0mm | 50,0mm | 30,0mm | 0 | tasseau_pin
 | L_T | L_T_2 | 1600,0mm | 50,0mm | 30,0mm | 0 | tasseau_pin
 | L_T | L_T_1 | 1600,0mm | 50,0mm | 30,0mm | 0 | tasseau_pin
 | L_M | L_M_4 | 1600,0mm | 50,0mm | 30,0mm | 0 | tasseau_pin
 | L_M | L_M_3 | 1600,0mm | 50,0mm | 30,0mm | 0 | tasseau_pin
 | L_M | L_M_2 | 1600,0mm | 50,0mm | 30,0mm | 0 | tasseau_pin
 | L_M | L_M_1 | 1600,0mm | 50,0mm | 30,0mm | 0 | tasseau_pin
 | L_P | L_P_4 | 1600,0mm | 50,0mm | 30,0mm | 0 | tasseau_pin
 | L_P | L_P_3 | 1600,0mm | 50,0mm | 30,0mm | 0 | tasseau_pin
 | L_P | L_P_2 | 1600,0mm | 50,0mm | 30,0mm | 0 | tasseau_pin
 | L_P | L_P_1 | 1600,0mm | 50,0mm | 30,0mm | 0 | tasseau_pin
 | ST_P_1 | ST_P_1_I_2 | 688,0mm | 24,0mm | 20,0mm | 0 | tasseau_pin
 | ST_P_1 | ST_P_1_I_1 | 688,0mm | 24,0mm | 20,0mm | 0 | tasseau_pin
 | ST_P_2 | ST_P_2_I_1 | 688,0mm | 24,0mm | 20,0mm | 0 | tasseau_pin
 | ST_P_2 | ST_P_2_I_2 | 688,0mm | 24,0mm | 20,0mm | 0 | tasseau_pin
 | ST_M_1 | ST_M_1_I_1 | 1660,0mm | 24,0mm | 20,0mm | 0 | tasseau_pin
 | ST_M_1 | ST_M_1_I_2 | 1660,0mm | 24,0mm | 20,0mm | 0 | tasseau_pin
 | ST_M_2 | ST_M_2_I_2 | 1660,0mm | 24,0mm | 20,0mm | 0 | tasseau_pin
 | ST_M_2 | ST_M_2_I_1 | 1660,0mm | 24,0mm | 20,0mm | 0 | tasseau_pin
 | ST_T | ST_T_I_2 | 1660,0mm | 24,0mm | 20,0mm | 0 | tasseau_pin
 | ST_T | ST_T_I_1 | 1660,0mm | 24,0mm | 20,0mm | 0 | tasseau_pin
 | A_2_P | A_2_P_3 | 710,0mm | 95,0mm | 10,0mm | 0 | contreplaquÃ©_pin
 | A_P_D_P | A_P_D_P_3 | 518,0mm | 95,0mm | 10,0mm | 0 | contreplaquÃ©_pin
 | SOC | SOC_P | 710,0mm | 580,0mm | 10,0mm | 0 | contreplaquÃ©_pin
 | A_2_P | A_2_P_1 | 710,0mm | 195,0mm | 10,0mm | 0 | contreplaquÃ©_pin
 | A_P_D_P | A_P_D_P_1 | 518,0mm | 195,0mm | 10,0mm | 0 | contreplaquÃ©_pin
 | A_2_P | A_2_P_2 | 710,0mm | 180,0mm | 10,0mm | 0 | contreplaquÃ©_pin
 | A_P_D_P | A_P_D_P_2 | 518,0mm | 180,0mm | 10,0mm | 0 | contreplaquÃ©_pin
 | A_2_C | A_2_H_3 | 780,0mm | 50,0mm | 24,0mm | 0 | massif_hetre
 | A_2_C | A_2_H_6 | 780,0mm | 50,0mm | 24,0mm | 0 | massif_hetre
 | A_2_C | A_2_H_4 | 780,0mm | 50,0mm | 24,0mm | 0 | massif_hetre
 | A_2_C | A_2_H_5 | 780,0mm | 50,0mm | 24,0mm | 0 | massif_hetre
 | A_1 | A_1_H_6 | 780,0mm | 50,0mm | 24,0mm | 0 | massif_hetre
 | A_1 | A_1_H_3 | 780,0mm | 50,0mm | 24,0mm | 0 | massif_hetre
 | A_1 | A_1_H_5 | 780,0mm | 50,0mm | 24,0mm | 0 | massif_hetre
 | A_1 | A_1_H_4 | 780,0mm | 50,0mm | 24,0mm | 0 | massif_hetre
" | A_P_D_C | A_P_D_H_3 | 588,0mm | 50,0mm | 24,0mm | 0 | massif_hetre
 | A_P_D_C | A_P_D_H_2 | 588,0mm | 50,0mm | 24,0mm | 0 | massif_hetre
 | A_2_C | A_2_H_2 | 780,0mm | 100,0mm | 24,0mm | 0 | massif_hetre
 | A_2_C | A_2_H_1 | 780,0mm | 100,0mm | 24,0mm | 0 | massif_hetre
 | A_2_C | A_2_H_8 | 780,0mm | 100,0mm | 24,0mm | 0 | massif_hetre
 | A_2_C | A_2_H_7 | 780,0mm | 100,0mm | 24,0mm | 0 | massif_hetre
 | A_1 | A_1_H_2 | 780,0mm | 100,0mm | 24,0mm | 0 | massif_hetre
 | A_1 | A_1_H_8 | 780,0mm | 100,0mm | 24,0mm | 0 | massif_hetre
 | A_1 | A_1_H_7 | 780,0mm | 100,0mm | 24,0mm | 0 | massif_hetre
 | A_1 | A_1_H_1 | 780,0mm | 100,0mm | 24,0mm | 0 | massif_hetre
 | SOC | SOC_TP_2 | 750,0mm | 100,0mm | 24,0mm | 0 | massif_hetre
 | A_P_D_C | A_P_D_V_2 | 680,0mm | 100,0mm | 24,0mm | 0 | massif_hetre
 | A_P_D_C | A_P_D_V_1 | 680,0mm | 100,0mm | 24,0mm | 0 | massif_hetre
 | A_2_C | A_2_V_1 | 680,0mm | 100,0mm | 24,0mm | 0 | massif_hetre
 | A_2_C | A_2_V_3 | 680,0mm | 100,0mm | 24,0mm | 0 | massif_hetre
 | A_2_C | A_2_V_2 | 680,0mm | 100,0mm | 24,0mm | 0 | massif_hetre
 | A_1 | A_1_V_1 | 680,0mm | 100,0mm | 24,0mm | 0 | massif_hetre
 | A_1 | A_1_V_3 | 680,0mm | 100,0mm | 24,0mm | 0 | massif_hetre
 | A_1 | A_1_V_2 | 680,0mm | 100,0mm | 24,0mm | 0 | massif_hetre
 | A_P_D_C | A_P_D_H_1 | 588,0mm | 100,0mm | 24,0mm | 0 | massif_hetre
 | A_P_D_C | A_P_D_H_4 | 588,0mm | 100,0mm | 24,0mm | 0 | massif_hetre
 | SOC | SOC_TP_1 | 2060,0mm | 100,0mm | 24,0mm | 0 | massif_hetre
 | SOC | SOC_TP_3 | 2060,0mm | 100,0mm | 24,0mm | 0 | massif_hetre
 | SOC | SOC_GD_2 | 1660,0mm | 100,0mm | 24,0mm | 0 | massif_hetre
 | SOC | SOC_GD_4 | 1660,0mm | 100,0mm | 24,0mm | 0 | massif_hetre
 | SOC | SOC_GD_3 | 1660,0mm | 100,0mm | 24,0mm | 0 | massif_hetre
 | SOC | SOC_GD_1 | 1660,0mm | 100,0mm | 24,0mm | 0 | massif_hetre
 | A_PI | A_PI_2_D | 704,0mm | 65,0mm | 20,0mm | 0 | massif_hetre
 | A_PI | A_PI_2_G | 704,0mm | 65,0mm | 20,0mm | 0 | massif_hetre
 | A_PI | A_PI_3_D | 704,0mm | 25,0mm | 20,0mm | 0 | massif_hetre
 | A_PI | A_PI_3_G | 704,0mm | 25,0mm | 20,0mm | 0 | massif_hetre
 | ST_P_1 | ST_P_1_F_1 | 794,0mm | 100,0mm | 20,0mm | 0 | massif_hetre
 | ST_P_2 | ST_P_2_F_1 | 794,0mm | 100,0mm | 20,0mm | 0 | massif_hetre
 | ST_M_1 | ST_M_1_F_2 | 650,0mm | 100,0mm | 20,0mm | 0 | massif_hetre
 | ST_M_1 | ST_M_1_F_1 | 650,0mm | 100,0mm | 20,0mm | 0 | massif_hetre
 | ST_M_2 | ST_M_2_F_2 | 650,0mm | 100,0mm | 20,0mm | 0 | massif_hetre
 | ST_M_2 | ST_M_2_F_1 | 650,0mm | 100,0mm | 20,0mm | 0 | massif_hetre
 | ST_T | ST_T_F_2 | 650,0mm | 100,0mm | 20,0mm | 0 | massif_hetre
 | ST_T | ST_T_F_1 | 650,0mm | 100,0mm | 20,0mm | 0 | massif_hetre
 | C_D | C_D_3_P | 410,0mm | 100,0mm | 30,0mm | 0 | massif_sipo
 | C_D | C_D_3_T | 410,0mm | 100,0mm | 30,0mm | 0 | massif_sipo
 | C_G | C_G_3_T | 410,0mm | 100,0mm | 30,0mm | 0 | massif_sipo
 | C_G | C_G_3_P | 410,0mm | 100,0mm | 30,0mm | 0 | massif_sipo
 | C_P | C_P_4_D | 410,0mm | 100,0mm | 30,0mm | 0 | massif_sipo
 | C_P | C_P_4_G | 410,0mm | 100,0mm | 30,0mm | 0 | massif_sipo
 | C_D | C_D_1 | 2060,0mm | 100,0mm | 30,0mm | 0,01 | massif_sipo
 | C_D | C_D_2 | 2060,0mm | 100,0mm | 30,0mm | 0,01 | massif_sipo
 | C_G | C_G_1 | 2060,0mm | 100,0mm | 30,0mm | 0,01 | massif_sipo
 | C_G | C_G_2 | 2060,0mm | 100,0mm | 30,0mm | 0,01 | massif_sipo
 | C_P | C_P_2 | 1660,0mm | 100,0mm | 30,0mm | 0 | massif_sipo
 | C_P | C_P_1 | 1660,0mm | 100,0mm | 30,0mm | 0 | massif_sipo
 | A_T_C | A_T_H_3 | 780,0mm | 50,0mm | 24,0mm | 0 | massif_sipo
 | A_T_C | A_T_H_4 | 780,0mm | 50,0mm | 24,0mm | 0 | massif_sipo
 | A_P_G_C | A_P_G_H_2 | 588,0mm | 50,0mm | 24,0mm | 0 | massif_sipo
 | A_P_G_C | A_P_G_H_3 | 588,0mm | 50,0mm | 24,0mm | 0 | massif_sipo
 | A_T_C | A_T_H_8 | 780,0mm | 100,0mm | 24,0mm | 0 | massif_sipo
 | A_T_C | A_T_H_7 | 780,0mm | 100,0mm | 24,0mm | 0 | massif_sipo
 | A_T_C | A_T_H_2 | 780,0mm | 100,0mm | 24,0mm | 0 | massif_sipo
 | A_T_C | A_T_H_1 | 780,0mm | 100,0mm | 24,0mm | 0 | massif_sipo
 | A_T_C | A_T_V_1 | 680,0mm | 100,0mm | 24,0mm | 0 | massif_sipo
 | A_T_C | A_T_V_3 | 680,0mm | 100,0mm | 24,0mm | 0 | massif_sipo
 | A_T_C | A_T_V_2 | 680,0mm | 100,0mm | 24,0mm | 0 | massif_sipo
 | A_P_G_C | A_P_G_V_2 | 680,0mm | 100,0mm | 24,0mm | 0 | massif_sipo
 | A_P_G_C | A_P_G_V_1 | 680,0mm | 100,0mm | 24,0mm | 0 | massif_sipo
 | A_P_G_C | A_P_G_H_1 | 588,0mm | 100,0mm | 24,0mm | 0 | massif_sipo
 | A_P_G_C | A_P_G_H_4 | 588,0mm | 100,0mm | 24,0mm | 0 | massif_sipo
 | C_T | C_T_1 | 1660,0mm | 100,0mm | 24,0mm | 0 | massif_sipo
 | C_T | C_T_2 | 1660,0mm | 100,0mm | 24,0mm | 0 | massif_sipo
 | C_T | C_T_3 | 1660,0mm | 100,0mm | 24,0mm | 0 | massif_sipo
 | C_T | C_T_4 | 1660,0mm | 100,0mm | 24,0mm | 0 | massif_sipo
 | A_PI | A_PI_1 | 704,0mm | 85,0mm | 20,0mm | 0 | massif_sipo
 | A_T_P | A_T_P_3_3 | 710,0mm | 95,0mm | 10,0mm | 0 | massif_sipo
 | A_T_P | A_T_P_4_3 | 710,0mm | 95,0mm | 10,0mm | 0 | massif_sipo
 | A_T_P | A_T_P_2_2 | 710,0mm | 95,0mm | 10,0mm | 0 | massif_sipo
 | A_T_P | A_T_P_1_2 | 710,0mm | 95,0mm | 10,0mm | 0 | massif_sipo
 | A_P_G_P | A_P_G_C_1_2 | 518,0mm | 95,0mm | 10,0mm | 0 | massif_sipo
 | A_P_G_P | A_P_G_C_3 | 518,0mm | 95,0mm | 10,0mm | 0 | massif_sipo
 | A_P_G_P | A_P_G_C_2_2 | 518,0mm | 90,0mm | 10,0mm | 0 | massif_sipo
 | A_T_P | A_T_P_4_1 | 710,0mm | 110,0mm | 10,0mm | 0 | massif_sipo
 | A_T_P | A_T_P_4_2 | 710,0mm | 110,0mm | 10,0mm | 0 | massif_sipo
 | A_T_P | A_T_P_3_2 | 710,0mm | 110,0mm | 10,0mm | 0 | massif_sipo
 | A_T_P | A_T_P_2_1 | 710,0mm | 110,0mm | 10,0mm | 0 | massif_sipo
 | A_T_P | A_T_P_1_1 | 710,0mm | 110,0mm | 10,0mm | 0 | massif_sipo
 | A_T_P | A_T_P_3_1 | 710,0mm | 110,0mm | 10,0mm | 0 | massif_sipo
 | A_P_G_P | A_P_G_C_1_1 | 518,0mm | 110,0mm | 10,0mm | 0 | massif_sipo
 | A_P_G_P | A_P_G_C_2_1 | 518,0mm | 100,0mm | 10,0mm | 0 | massif_sipo

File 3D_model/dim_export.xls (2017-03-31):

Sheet: Feuille1_3
Components
Part # | Sub-Assembly | Description | Length(L) | Width(W) | Thickness(T) | Cubic m | Material
C-001-01 | SOC | SOC_GD_2 | 1660,0mm | 100,0mm | 24,0mm | 0.003984 | massif_hetre
C-002-01 | SOC | SOC_GD_4 | 1660,0mm | 100,0mm | 24,0mm | 0.003984 | massif_hetre
C-003-01 | SOC | SOC_TP_1 | 2060,0mm | 100,0mm | 24,0mm | 0.004944 | massif_hetre
C-004-01 | SOC | SOC_GD_3 | 1660,0mm | 100,0mm | 24,0mm | 0.003984 | massif_hetre
C-005-01 | SOC | SOC_P | 710,0mm | 580,0mm | 10,0mm | 0.004118 | contreplaquÃ©_pin
C-006-01 | SOC | SOC_TP_3 | 2060,0mm | 100,0mm | 24,0mm | 0.004944 | massif_hetre
C-007-01 | SOC | SOC_TP_2 | 750,0mm | 100,0mm | 24,0mm | 0.0018 | massif_hetre
C-008-01 | SOC | SOC_GD_1 | 1660,0mm | 100,0mm | 24,0mm | 0.003984 | massif_hetre
C-009-01 | L_T | L_T_4 | 1600,0mm | 50,0mm | 30,0mm | 0.0024 | tasseau_pin
C-010-01 | L_T | L_T_3 | 1600,0mm | 50,0mm | 30,0mm | 0.0024 | tasseau_pin
C-011-01 | L_T | L_T_2 | 1600,0mm | 50,0mm | 30,0mm | 0.0024 | tasseau_pin
C-012-01 | L_T | L_T_1 | 1600,0mm | 50,0mm | 30,0mm | 0.0024 | tasseau_pin
C-013-01 | L_M | L_M_4 | 1600,0mm | 50,0mm | 30,0mm | 0.0024 | tasseau_pin
C-014-01 | L_M | L_M_3 | 1600,0mm | 50,0mm | 30,0mm | 0.0024 | tasseau_pin
C-015-01 | L_M | L_M_2 | 1600,0mm | 50,0mm | 30,0mm | 0.0024 | tasseau_pin
C-016-01 | L_M | L_M_1 | 1600,0mm | 50,0mm | 30,0mm | 0.0024 | tasseau_pin
C-017-01 | L_P | L_P_4 | 1600,0mm | 50,0mm | 30,0mm | 0.0024 | tasseau_pin
C-018-01 | L_P | L_P_3 | 1600,0mm | 50,0mm | 30,0mm | 0.0024 | tasseau_pin
C-019-01 | L_P | L_P_2 | 1600,0mm | 50,0mm | 30,0mm | 0.0024 | tasseau_pin
C-020-01 | L_P | L_P_1 | 1600,0mm | 50,0mm | 30,0mm | 0.0024 | tasseau_pin
C-021-01 | LS | LS_D | 2006,0mm | 50,0mm | 50,0mm | 0.005015 | tasseau_pin
C-022-01 | LS | LS_T | 100,0mm | 50,0mm | 50,0mm | 0.00025 | tasseau_pin
C-023-01 | LS | LS_G | 2006,0mm | 50,0mm | 50,0mm | 0.005015 | tasseau_pin
C-024-01 | LS | LS_M | 2006,0mm | 50,0mm | 50,0mm | 0.005015 | tasseau_pin
C-025-01 | LS | LS_P | 100,0mm | 50,0mm | 50,0mm | 0.00025 | tasseau_pin
C-026-01 | ST_P_1 | ST_P_1_I_2 | 688,0mm | 24,0mm | 20,0mm | 0.00033 | tasseau_pin
C-027-01 | ST_P_1 | ST_P_1_I_1 | 688,0mm | 24,0mm | 20,0mm | 0.00033 | tasseau_pin
C-028-01 | ST_P_1 | ST_P_1_F_1 | 794,0mm | 100,0mm | 20,0mm | 0.001588 | massif_hetre
C-029-01 | ST_P_2 | ST_P_2_I_1 | 688,0mm | 24,0mm | 20,0mm | 0.00033 | tasseau_pin
C-030-01 | ST_P_2 | ST_P_2_I_2 | 688,0mm | 24,0mm | 20,0mm | 0.00033 | tasseau_pin
C-031-01 | ST_P_2 | ST_P_2_F_1 | 794,0mm | 100,0mm | 20,0mm | 0.001588 | massif_hetre
C-032-01 | ST_M_1 | ST_M_1_F_2 | 650,0mm | 100,0mm | 20,0mm | 0.0013 | massif_hetre
C-033-01 | ST_M_1 | ST_M_1_I_1 | 1660,0mm | 24,0mm | 20,0mm | 0.000797 | tasseau_pin
C-034-01 | ST_M_1 | ST_M_1_F_1 | 650,0mm | 100,0mm | 20,0mm | 0.0013 | massif_hetre
C-035-01 | ST_M_1 | ST_M_1_I_2 | 1660,0mm | 24,0mm | 20,0mm | 0.000797 | tasseau_pin
C-036-01 | ST_M_2 | ST_M_2_F_2 | 650,0mm | 100,0mm | 20,0mm | 0.0013 | massif_hetre
C-037-01 | ST_M_2 | ST_M_2_I_2 | 1660,0mm | 24,0mm | 20,0mm | 0.000797 | tasseau_pin
C-038-01 | ST_M_2 | ST_M_2_I_1 | 1660,0mm | 24,0mm | 20,0mm | 0.000797 | tasseau_pin
C-039-01 | ST_M_2 | ST_M_2_F_1 | 650,0mm | 100,0mm | 20,0mm | 0.0013 | massif_hetre
C-040-01 | ST_T | ST_T_F_2 | 650,0mm | 100,0mm | 20,0mm | 0.0013 | massif_hetre
C-041-01 | ST_T | ST_T_F_1 | 650,0mm | 100,0mm | 20,0mm | 0.0013 | massif_hetre
C-042-01 | ST_T | ST_T_I_2 | 1660,0mm | 24,0mm | 20,0mm | 0.000797 | tasseau_pin
C-043-01 | ST_T | ST_T_I_1 | 1660,0mm | 24,0mm | 20,0mm | 0.000797 | tasseau_pin
C-044-01 | C_T | C_T_1 | 1660,0mm | 100,0mm | 24,0mm | 0.003984 | massif_sipo
C-045-01 | C_T | C_T_2 | 1660,0mm | 100,0mm | 24,0mm | 0.003984 | massif_sipo
C-046-01 | C_T | C_T_3 | 1660,0mm | 100,0mm | 24,0mm | 0.003984 | massif_sipo
C-047-01 | C_T | C_T_4 | 1660,0mm | 100,0mm | 24,0mm | 0.003984 | massif_sipo
C-048-01 | C_D | C_D_1 | 2060,0mm | 100,0mm | 30,0mm | 0.00618 | massif_sipo
C-049-01 | C_D | C_D_2 | 2060,0mm | 100,0mm | 30,0mm | 0.00618 | massif_sipo
C-050-01 | C_D | C_D_3_P | 410,0mm | 100,0mm | 30,0mm | 0.00123 | massif_sipo
C-051-01 | C_D | C_D_3_T | 410,0mm | 100,0mm | 30,0mm | 0.00123 | massif_sipo
C-052-01 | C_G | C_G_1 | 2060,0mm | 100,0mm | 30,0mm | 0.00618 | massif_sipo
C-053-01 | C_G | C_G_2 | 2060,0mm | 100,0mm | 30,0mm | 0.00618 | massif_sipo
C-054-01 | C_G | C_G_3_T | 410,0mm | 100,0mm | 30,0mm | 0.00123 | massif_sipo
C-055-01 | C_G | C_G_3_P | 410,0mm | 100,0mm | 30,0mm | 0.00123 | massif_sipo
C-056-01 | C_P | C_P_2 | 1660,0mm | 100,0mm | 30,0mm | 0.00498 | massif_sipo
C-057-01 | C_P | C_P_4_D | 410,0mm | 100,0mm | 30,0mm | 0.00123 | massif_sipo
C-058-01 | C_P | C_P_1 | 1660,0mm | 100,0mm | 30,0mm | 0.00498 | massif_sipo
C-059-01 | C_P | C_P_4_G | 410,0mm | 100,0mm | 30,0mm | 0.00123 | massif_sipo
C-060-01 | A_T_C | A_T_H_8 | 780,0mm | 100,0mm | 24,0mm | 0.001872 | massif_sipo
C-061-01 | A_T_C | A_T_V_1 | 680,0mm | 100,0mm | 24,0mm | 0.001632 | massif_sipo
C-062-01 | A_T_C | A_T_V_3 | 680,0mm | 100,0mm | 24,0mm | 0.001632 | massif_sipo
C-063-01 | A_T_C | A_T_V_2 | 680,0mm | 100,0mm | 24,0mm | 0.001632 | massif_sipo
C-064-01 | A_T_C | A_T_H_7 | 780,0mm | 100,0mm | 24,0mm | 0.001872 | massif_sipo
C-065-01 | A_T_C | A_T_H_2 | 780,0mm | 100,0mm | 24,0mm | 0.001872 | massif_sipo
C-066-01 | A_T_C | A_T_H_1 | 780,0mm | 100,0mm | 24,0mm | 0.001872 | massif_sipo
C-067-01 | A_T_C | A_T_H_3 | 780,0mm | 50,0mm | 24,0mm | 0.000936 | massif_sipo
C-068-01 | A_T_C | A_T_H_4 | 780,0mm | 50,0mm | 24,0mm | 0.000936 | massif_sipo
C-069-01 | A_T_P | A_T_P_3_3 | 710,0mm | 95,0mm | 10,0mm | 0.000675 | massif_sipo
C-070-01 | A_T_P | A_T_P_4_1 | 710,0mm | 110,0mm | 10,0mm | 0.000781 | massif_sipo
C-071-01 | A_T_P | A_T_P_4_2 | 710,0mm | 110,0mm | 10,0mm | 0.000781 | massif_sipo
C-072-01 | A_T_P | A_T_P_4_3 | 710,0mm | 95,0mm | 10,0mm | 0.000675 | massif_sipo
C-073-01 | A_T_P | A_T_P_2_2 | 710,0mm | 95,0mm | 10,0mm | 0.000675 | massif_sipo
C-074-01 | A_T_P | A_T_P_3_2 | 710,0mm | 110,0mm | 10,0mm | 0.000781 | massif_sipo
C-075-01 | A_T_P | A_T_P_2_1 | 710,0mm | 110,0mm | 10,0mm | 0.000781 | massif_sipo
C-076-01 | A_T_P | A_T_P_1_2 | 710,0mm | 95,0mm | 10,0mm | 0.000675 | massif_sipo
C-077-01 | A_T_P | A_T_P_1_1 | 710,0mm | 110,0mm | 10,0mm | 0.000781 | massif_sipo
C-078-01 | A_T_P | A_T_P_3_1 | 710,0mm | 110,0mm | 10,0mm | 0.000781 | massif_sipo
C-079-01 | A_P_G_C | A_P_G_H_2 | 588,0mm | 50,0mm | 24,0mm | 0.000706 | massif_sipo
C-080-01 | A_P_G_C | A_P_G_H_3 | 588,0mm | 50,0mm | 24,0mm | 0.000706 | massif_sipo
C-081-01 | A_P_G_C | A_P_G_V_2 | 680,0mm | 100,0mm | 24,0mm | 0.001632 | massif_sipo
C-082-01 | A_P_G_C | A_P_G_V_1 | 680,0mm | 100,0mm | 24,0mm | 0.001632 | massif_sipo
C-083-01 | A_P_G_C | A_P_G_H_1 | 588,0mm | 100,0mm | 24,0mm | 0.001411 | massif_sipo
C-084-01 | A_P_G_C | A_P_G_H_4 | 588,0mm | 100,0mm | 24,0mm | 0.001411 | massif_sipo
C-085-01 | A_P_G_P | A_P_G_C_1_1 | 518,0mm | 110,0mm | 10,0mm | 0.00057 | massif_sipo
C-086-01 | A_P_G_P | A_P_G_C_1_2 | 518,0mm | 95,0mm | 10,0mm | 0.000492 | massif_sipo
C-087-01 | A_P_G_P | A_P_G_C_3 | 518,0mm | 95,0mm | 10,0mm | 0.000492 | massif_sipo
C-088-01 | A_P_G_P | A_P_G_C_2_2 | 518,0mm | 90,0mm | 10,0mm | 0.000466 | massif_sipo
C-089-01 | A_P_G_P | A_P_G_C_2_1 | 518,0mm | 100,0mm | 10,0mm | 0.000518 | massif_sipo
C-090-01 | A_P_D_C | A_P_D_H_3 | 588,0mm | 50,0mm | 24,0mm | 0.000706 | massif_hetre
C-091-01 | A_P_D_C | A_P_D_H_2 | 588,0mm | 50,0mm | 24,0mm | 0.000706 | massif_hetre
C-092-01 | A_P_D_C | A_P_D_H_1 | 588,0mm | 100,0mm | 24,0mm | 0.001411 | massif_hetre
C-093-01 | A_P_D_C | A_P_D_V_2 | 680,0mm | 100,0mm | 24,0mm | 0.001632 | massif_hetre
C-094-01 | A_P_D_C | A_P_D_V_1 | 680,0mm | 100,0mm | 24,0mm | 0.001632 | massif_hetre
C-095-01 | A_P_D_C | A_P_D_H_4 | 588,0mm | 100,0mm | 24,0mm | 0.001411 | massif_hetre
C-096-01 | A_P_D_P | A_P_D_P_2 | 518,0mm | 180,0mm | 10,0mm | 0.000932 | contreplaquÃ©_pin
C-097-01 | A_P_D_P | A_P_D_P_1 | 518,0mm | 195,0mm | 10,0mm | 0.00101 | contreplaquÃ©_pin
C-098-01 | A_P_D_P | A_P_D_P_3 | 518,0mm | 95,0mm | 10,0mm | 0.000492 | contreplaquÃ©_pin
C-099-01 | A_2_C | A_2_H_2 | 780,0mm | 100,0mm | 24,0mm | 0.001872 | massif_hetre
C-100-01 | A_2_C | A_2_V_1 | 680,0mm | 100,0mm | 24,0mm | 0.001632 | massif_hetre
C-101-01 | A_2_C | A_2_H_1 | 780,0mm | 100,0mm | 24,0mm | 0.001872 | massif_hetre
C-102-01 | A_2_C | A_2_H_8 | 780,0mm | 100,0mm | 24,0mm | 0.001872 | massif_hetre
C-103-01 | A_2_C | A_2_V_3 | 680,0mm | 100,0mm | 24,0mm | 0.001632 | massif_hetre
C-104-01 | A_2_C | A_2_H_3 | 780,0mm | 50,0mm | 24,0mm | 0.000936 | massif_hetre
C-105-01 | A_2_C | A_2_H_6 | 780,0mm | 50,0mm | 24,0mm | 0.000936 | massif_hetre
C-106-01 | A_2_C | A_2_H_7 | 780,0mm | 100,0mm | 24,0mm | 0.001872 | massif_hetre
C-107-01 | A_2_C | A_2_V_2 | 680,0mm | 100,0mm | 24,0mm | 0.001632 | massif_hetre
C-108-01 | A_2_C | A_2_H_4 | 780,0mm | 50,0mm | 24,0mm | 0.000936 | massif_hetre
C-109-01 | A_2_C | A_2_H_5 | 780,0mm | 50,0mm | 24,0mm | 0.000936 | massif_hetre
C-110-01 | A_2_P | A_2_P_2 | 710,0mm | 180,0mm | 10,0mm | 0.001278 | contreplaquÃ©_pin
C-111-01 | A_2_P | A_2_P_1 | 710,0mm | 195,0mm | 10,0mm | 0.001385 | contreplaquÃ©_pin
C-112-01 | A_2_P | A_2_P_3 | 710,0mm | 95,0mm | 10,0mm | 0.000675 | contreplaquÃ©_pin
C-113-01 | A_1 | A_1_H_2 | 780,0mm | 100,0mm | 24,0mm | 0.001872 | massif_hetre
C-114-01 | A_1 | A_1_V_1 | 680,0mm | 100,0mm | 24,0mm | 0.001632 | massif_hetre
C-115-01 | A_1 | A_1_H_8 | 780,0mm | 100,0mm | 24,0mm | 0.001872 | massif_hetre
C-116-01 | A_1 | A_1_H_6 | 780,0mm | 50,0mm | 24,0mm | 0.000936 | massif_hetre
C-117-01 | A_1 | A_1_H_3 | 780,0mm | 50,0mm | 24,0mm | 0.000936 | massif_hetre
C-118-01 | A_1 | A_1_H_5 | 780,0mm | 50,0mm | 24,0mm | 0.000936 | massif_hetre
C-119-01 | A_1 | A_1_V_3 | 680,0mm | 100,0mm | 24,0mm | 0.001632 | massif_hetre
C-120-01 | A_1 | A_1_H_7 | 780,0mm | 100,0mm | 24,0mm | 0.001872 | massif_hetre
C-121-01 | A_1 | A_1_H_1 | 780,0mm | 100,0mm | 24,0mm | 0.001872 | massif_hetre
C-122-01 | A_1 | A_1_H_4 | 780,0mm | 50,0mm | 24,0mm | 0.000936 | massif_hetre
C-123-01 | A_1 | A_1_V_2 | 680,0mm | 100,0mm | 24,0mm | 0.001632 | massif_hetre
C-124-01 | A_PI | A_PI_2_D | 704,0mm | 65,0mm | 20,0mm | 0.000915 | massif_hetre
C-125-01 | A_PI | A_PI_3_D | 704,0mm | 25,0mm | 20,0mm | 0.000352 | massif_hetre
C-126-01 | A_PI | A_PI_3_G | 704,0mm | 25,0mm | 20,0mm | 0.000352 | massif_hetre
C-127-01 | A_PI | A_PI_2_G | 704,0mm | 65,0mm | 20,0mm | 0.000915 | massif_hetre
C-128-01 | A_PI | A_PI_1 | 704,0mm | 85,0mm | 20,0mm | 0.001197 | massif_sipo
Total Component Cubic m
0.2321
Component Materials
Material | Cubic m
massif_hetre | 0.0809
contreplaquÃ©_pin | 0.0099
tasseau_pin | 0.0504
massif_sipo | 0.0909

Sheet: Feuille1
densité | min | max | vol | poids | prix /m3 | prix
sapelli | 0.6 | 0.75 | 0.1109 | 74.8575 | 1150 | 127.535
hetre | 0.8 | 0.9 | 0.0849 | 72.165 | 760 | 64.524
pin | 0.4 | 0.5 | 0.0061 | 2.745

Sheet: Sheet1
Description | Quantité | Longueur mm | Largeur mm | Epaisseur mm | Total Length (m) | Material
support_tiroir | 4 | 680.6 | 24 | 20 | 2.7224 | tasseau_pin
support_tiroir | 6 | 1660 | 24 | 20 | 9.96 | tasseau_pin
panneautage_pin | 1 | 518 | 180 | 10 | 0.518 | contreplaqué_pin
panneautage_pin | 1 | 710 | 180 | 10 | 0.71 | contreplaqué_pin
panneautage_pin | 1 | 518 | 195 | 10 | 0.518 | contreplaqué_pin
panneautage_pin | 1 | 710 | 195 | 10 | 0.71 | contreplaqué_pin
panneautage_pin | 1 | 710 | 580 | 10 | 0.71 | contreplaqué_pin
panneautage_pin | 1 | 518 | 95 | 10 | 0.518 | contreplaqué_pin
panneautage_pin | 1 | 710 | 95 | 10 | 0.71 | contreplaqué_pin
trait_facade_hetre | 2 | 650 | 20 | 10 | 1.3 | massif_hetre
pied_2 | 2 | 704 | 25 | 20 | 1.408 | massif_hetre
pied_1 | 2 | 704 | 64.9 | 20 | 1.408 | massif_hetre
suport_tiroir_visi | 6 | 650 | 100 | 20 | 3.9 | massif_hetre
suport_tiroir_visi | 2 | 794 | 100 | 20 | 1.588 | massif_hetre
cloison_cadre_hb | 6 | 680 | 100 | 24 | 4.08 | massif_hetre
cloison_inter_gd_b | 8 | 780 | 100 | 24 | 6.24 | massif_hetre
cloison_inter_gd_b#1 | 2 | 588 | 100 | 24 | 1.176 | massif_hetre
cloison_inter_hb_m | 2 | 680 | 100 | 24 | 1.36 | massif_hetre
socle_G | 2 | 2060 | 100 | 24 | 4.12 | massif_hetre
socle_h | 4 | 1660 | 100 | 24 | 6.64 | massif_hetre
socle_hb | 1 | 750 | 100 | 24 | 0.75 | massif_hetre
cloison_inter | 8 | 780 | 50 | 24 | 6.24 | massif_hetre
cloison_traverse_avt_arreire | 2 | 588 | 50 | 24 | 1.176 | massif_hetre
panneautage_lateral | 1 | 518 | 100 | 10 | 0.518 | massif_sipo
cloison_panneauté | 2 | 710 | 110 | 10 | 1.42 | massif_sipo
cloison_panneauté | 2 | 710 | 110 | 10 | 1.42 | massif_sipo
cloison_panneauté | 2 | 710 | 110 | 10 | 1.42 | massif_sipo
panneautage_lateral | 2 | 518 | 110 | 10 | 1.036 | massif_sipo
cloison_exterieur | 1 | 518 | 195 | 10 | 0.518 | massif_sipo
panneautage_lateral | 1 | 518 | 90 | 10 | 0.518 | massif_sipo
panneautage_lateral | 1 | 518 | 94.7 | 10 | 0.518 | massif_sipo
cloison_panneauté | 1 | 710 | 95 | 10 | 0.71 | massif_sipo
cloison_panneauté | 2 | 710 | 95 | 10 | 1.42 | massif_sipo
cloison_panneauté | 1 | 710 | 95 | 10 | 0.71 | massif_sipo
facade_tiroir | 24 | 650 | 95 | 10 | 15.6 | massif_sipo
pied_central_rotate | 1 | 704 | 84.9 | 20 | 0.704 | massif_sipo
cloison_cadre_hb#1 | 1 | 680 | 100 | 24 | 0.68 | massif_sipo
cloison_cadre_hb#2 | 1 | 680 | 100 | 24 | 0.68 | massif_sipo
cloison_inter_gd_b#2 | 2 | 588 | 100 | 24 | 1.176 | massif_sipo
tete_de_lit_24 | 4 | 1660 | 100 | 24 | 6.64 | massif_sipo
tete_de_lit_cadre | 4 | 780 | 100 | 24 | 3.12 | massif_sipo
tete_lit_cadre | 3 | 680 | 100 | 24 | 2.04 | massif_sipo
cloison_traverse_avt_arreire#1 | 1 | 588 | 50 | 24 | 0.588 | massif_sipo
cloison_traverse_avt_arreire#2 | 1 | 588 | 50 | 24 | 0.588 | massif_sipo
tete_de_lit_support | 2 | 780 | 50 | 24 | 1.56 | massif_sipo
traverse_avt_arreiere_stylisation | 4 | 407 | 100 | 30 | 1.628 | massif_sipo
traverse_avt_arreiere_stylisation#1 | 2 | 434.3 | 100 | 30 | 0.8686 | massif_sipo
traverse_avt_arriere_long | 6 | 2060 | 100 | 30 | 12.36 | massif_sipo

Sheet: Sheet2
 | Sub-Assembly | Description | Length(L) | Width(W) | Thickness(T) | Cubic m | Material
 | LS | LS_D | 2006,0mm | 50,0mm | 50,0mm | 0.005015 | tasseau_pin
 | LS | LS_G | 2006,0mm | 50,0mm | 50,0mm | 0.005015 | tasseau_pin
 | LS | LS_M | 2006,0mm | 50,0mm | 50,0mm | 0.005015 | tasseau_pin
 | LS | LS_T | 100,0mm | 50,0mm | 50,0mm | 0.00025 | tasseau_pin
 | LS | LS_P | 100,0mm | 50,0mm | 50,0mm | 0.00025 | tasseau_pin
 | L_T | L_T_4 | 1600,0mm | 50,0mm | 30,0mm | 0.0024 | tasseau_pin
 | L_T | L_T_3 | 1600,0mm | 50,0mm | 30,0mm | 0.0024 | tasseau_pin
 | L_T | L_T_2 | 1600,0mm | 50,0mm | 30,0mm | 0.0024 | tasseau_pin
 | L_T | L_T_1 | 1600,0mm | 50,0mm | 30,0mm | 0.0024 | tasseau_pin
 | L_M | L_M_4 | 1600,0mm | 50,0mm | 30,0mm | 0.0024 | tasseau_pin
 | L_M | L_M_3 | 1600,0mm | 50,0mm | 30,0mm | 0.0024 | tasseau_pin
 | L_M | L_M_2 | 1600,0mm | 50,0mm | 30,0mm | 0.0024 | tasseau_pin
 | L_M | L_M_1 | 1600,0mm | 50,0mm | 30,0mm | 0.0024 | tasseau_pin
 | L_P | L_P_4 | 1600,0mm | 50,0mm | 30,0mm | 0.0024 | tasseau_pin
 | L_P | L_P_3 | 1600,0mm | 50,0mm | 30,0mm | 0.0024 | tasseau_pin
 | L_P | L_P_2 | 1600,0mm | 50,0mm | 30,0mm | 0.0024 | tasseau_pin
 | L_P | L_P_1 | 1600,0mm | 50,0mm | 30,0mm | 0.0024 | tasseau_pin
 | ST_P_1 | ST_P_1_I_2 | 688,0mm | 24,0mm | 20,0mm | 0.00033 | tasseau_pin
 | ST_P_1 | ST_P_1_I_1 | 688,0mm | 24,0mm | 20,0mm | 0.00033 | tasseau_pin
 | ST_P_2 | ST_P_2_I_1 | 688,0mm | 24,0mm | 20,0mm | 0.00033 | tasseau_pin
 | ST_P_2 | ST_P_2_I_2 | 688,0mm | 24,0mm | 20,0mm | 0.00033 | tasseau_pin
 | ST_M_1 | ST_M_1_I_1 | 1660,0mm | 24,0mm | 20,0mm | 0.000797 | tasseau_pin
 | ST_M_1 | ST_M_1_I_2 | 1660,0mm | 24,0mm | 20,0mm | 0.000797 | tasseau_pin
 | ST_M_2 | ST_M_2_I_2 | 1660,0mm | 24,0mm | 20,0mm | 0.000797 | tasseau_pin
 | ST_M_2 | ST_M_2_I_1 | 1660,0mm | 24,0mm | 20,0mm | 0.000797 | tasseau_pin
 | ST_T | ST_T_I_2 | 1660,0mm | 24,0mm | 20,0mm | 0.000797 | tasseau_pin
 | ST_T | ST_T_I_1 | 1660,0mm | 24,0mm | 20,0mm | 0.000797 | tasseau_pin
 | A_2_P | A_2_P_3 | 710,0mm | 95,0mm | 10,0mm | 0.000675 | contreplaquÃ©_pin
 | A_P_D_P | A_P_D_P_3 | 518,0mm | 95,0mm | 10,0mm | 0.000492 | contreplaquÃ©_pin
 | SOC | SOC_P | 710,0mm | 580,0mm | 10,0mm | 0.004118 | contreplaquÃ©_pin
 | A_2_P | A_2_P_1 | 710,0mm | 195,0mm | 10,0mm | 0.001385 | contreplaquÃ©_pin
 | A_P_D_P | A_P_D_P_1 | 518,0mm | 195,0mm | 10,0mm | 0.00101 | contreplaquÃ©_pin
 | A_2_P | A_2_P_2 | 710,0mm | 180,0mm | 10,0mm | 0.001278 | contreplaquÃ©_pin
 | A_P_D_P | A_P_D_P_2 | 518,0mm | 180,0mm | 10,0mm | 0.000932 | contreplaquÃ©_pin
 | A_2_C | A_2_H_3 | 780,0mm | 50,0mm | 24,0mm | 0.000936 | massif_hetre
 | A_2_C | A_2_H_6 | 780,0mm | 50,0mm | 24,0mm | 0.000936 | massif_hetre
 | A_2_C | A_2_H_4 | 780,0mm | 50,0mm | 24,0mm | 0.000936 | massif_hetre
 | A_2_C | A_2_H_5 | 780,0mm | 50,0mm | 24,0mm | 0.000936 | massif_hetre
 | A_1 | A_1_H_6 | 780,0mm | 50,0mm | 24,0mm | 0.000936 | massif_hetre
 | A_1 | A_1_H_3 | 780,0mm | 50,0mm | 24,0mm | 0.000936 | massif_hetre
 | A_1 | A_1_H_5 | 780,0mm | 50,0mm | 24,0mm | 0.000936 | massif_hetre
 | A_1 | A_1_H_4 | 780,0mm | 50,0mm | 24,0mm | 0.000936 | massif_hetre
" | A_P_D_C | A_P_D_H_3 | 588,0mm | 50,0mm | 24,0mm | 0.000706 | massif_hetre
 | A_P_D_C | A_P_D_H_2 | 588,0mm | 50,0mm | 24,0mm | 0.000706 | massif_hetre
 | A_2_C | A_2_H_2 | 780,0mm | 100,0mm | 24,0mm | 0.001872 | massif_hetre
 | A_2_C | A_2_H_1 | 780,0mm | 100,0mm | 24,0mm | 0.001872 | massif_hetre
 | A_2_C | A_2_H_8 | 780,0mm | 100,0mm | 24,0mm | 0.001872 | massif_hetre
 | A_2_C | A_2_H_7 | 780,0mm | 100,0mm | 24,0mm | 0.001872 | massif_hetre
 | A_1 | A_1_H_2 | 780,0mm | 100,0mm | 24,0mm | 0.001872 | massif_hetre
 | A_1 | A_1_H_8 | 780,0mm | 100,0mm | 24,0mm | 0.001872 | massif_hetre
 | A_1 | A_1_H_7 | 780,0mm | 100,0mm | 24,0mm | 0.001872 | massif_hetre
 | A_1 | A_1_H_1 | 780,0mm | 100,0mm | 24,0mm | 0.001872 | massif_hetre
 | SOC | SOC_TP_2 | 750,0mm | 100,0mm | 24,0mm | 0.0018 | massif_hetre
 | A_P_D_C | A_P_D_V_2 | 680,0mm | 100,0mm | 24,0mm | 0.001632 | massif_hetre
 | A_P_D_C | A_P_D_V_1 | 680,0mm | 100,0mm | 24,0mm | 0.001632 | massif_hetre
 | A_2_C | A_2_V_1 | 680,0mm | 100,0mm | 24,0mm | 0.001632 | massif_hetre
 | A_2_C | A_2_V_3 | 680,0mm | 100,0mm | 24,0mm | 0.001632 | massif_hetre
 | A_2_C | A_2_V_2 | 680,0mm | 100,0mm | 24,0mm | 0.001632 | massif_hetre
 | A_1 | A_1_V_1 | 680,0mm | 100,0mm | 24,0mm | 0.001632 | massif_hetre
 | A_1 | A_1_V_3 | 680,0mm | 100,0mm | 24,0mm | 0.001632 | massif_hetre
 | A_1 | A_1_V_2 | 680,0mm | 100,0mm | 24,0mm | 0.001632 | massif_hetre
 | A_P_D_C | A_P_D_H_1 | 588,0mm | 100,0mm | 24,0mm | 0.001411 | massif_hetre
 | A_P_D_C | A_P_D_H_4 | 588,0mm | 100,0mm | 24,0mm | 0.001411 | massif_hetre
 | SOC | SOC_TP_1 | 2060,0mm | 100,0mm | 24,0mm | 0.004944 | massif_hetre
 | SOC | SOC_TP_3 | 2060,0mm | 100,0mm | 24,0mm | 0.004944 | massif_hetre
 | SOC | SOC_GD_2 | 1660,0mm | 100,0mm | 24,0mm | 0.003984 | massif_hetre
 | SOC | SOC_GD_4 | 1660,0mm | 100,0mm | 24,0mm | 0.003984 | massif_hetre
 | SOC | SOC_GD_3 | 1660,0mm | 100,0mm | 24,0mm | 0.003984 | massif_hetre
 | SOC | SOC_GD_1 | 1660,0mm | 100,0mm | 24,0mm | 0.003984 | massif_hetre
 | A_PI | A_PI_2_D | 704,0mm | 65,0mm | 20,0mm | 0.000915 | massif_hetre
 | A_PI | A_PI_2_G | 704,0mm | 65,0mm | 20,0mm | 0.000915 | massif_hetre
 | A_PI | A_PI_3_D | 704,0mm | 25,0mm | 20,0mm | 0.000352 | massif_hetre
 | A_PI | A_PI_3_G | 704,0mm | 25,0mm | 20,0mm | 0.000352 | massif_hetre
 | ST_P_1 | ST_P_1_F_1 | 794,0mm | 100,0mm | 20,0mm | 0.001588 | massif_hetre
 | ST_P_2 | ST_P_2_F_1 | 794,0mm | 100,0mm | 20,0mm | 0.001588 | massif_hetre
 | ST_M_1 | ST_M_1_F_2 | 650,0mm | 100,0mm | 20,0mm | 0.0013 | massif_hetre
 | ST_M_1 | ST_M_1_F_1 | 650,0mm | 100,0mm | 20,0mm | 0.0013 | massif_hetre
 | ST_M_2 | ST_M_2_F_2 | 650,0mm | 100,0mm | 20,0mm | 0.0013 | massif_hetre
 | ST_M_2 | ST_M_2_F_1 | 650,0mm | 100,0mm | 20,0mm | 0.0013 | massif_hetre
 | ST_T | ST_T_F_2 | 650,0mm | 100,0mm | 20,0mm | 0.0013 | massif_hetre
 | ST_T | ST_T_F_1 | 650,0mm | 100,0mm | 20,0mm | 0.0013 | massif_hetre
 | C_D | C_D_3_P | 410,0mm | 100,0mm | 30,0mm | 0.00123 | massif_sipo
 | C_D | C_D_3_T | 410,0mm | 100,0mm | 30,0mm | 0.00123 | massif_sipo
 | C_G | C_G_3_T | 410,0mm | 100,0mm | 30,0mm | 0.00123 | massif_sipo
 | C_G | C_G_3_P | 410,0mm | 100,0mm | 30,0mm | 0.00123 | massif_sipo
 | C_P | C_P_4_D | 410,0mm | 100,0mm | 30,0mm | 0.00123 | massif_sipo
 | C_P | C_P_4_G | 410,0mm | 100,0mm | 30,0mm | 0.00123 | massif_sipo
 | C_D | C_D_1 | 2060,0mm | 100,0mm | 30,0mm | 0.00618 | massif_sipo
 | C_D | C_D_2 | 2060,0mm | 100,0mm | 30,0mm | 0.00618 | massif_sipo
 | C_G | C_G_1 | 2060,0mm | 100,0mm | 30,0mm | 0.00618 | massif_sipo
 | C_G | C_G_2 | 2060,0mm | 100,0mm | 30,0mm | 0.00618 | massif_sipo
 | C_P | C_P_2 | 1660,0mm | 100,0mm | 30,0mm | 0.00498 | massif_sipo
 | C_P | C_P_1 | 1660,0mm | 100,0mm | 30,0mm | 0.00498 | massif_sipo
 | A_T_C | A_T_H_3 | 780,0mm | 50,0mm | 24,0mm | 0.000936 | massif_sipo
 | A_T_C | A_T_H_4 | 780,0mm | 50,0mm | 24,0mm | 0.000936 | massif_sipo
 | A_P_G_C | A_P_G_H_2 | 588,0mm | 50,0mm | 24,0mm | 0.000706 | massif_sipo
 | A_P_G_C | A_P_G_H_3 | 588,0mm | 50,0mm | 24,0mm | 0.000706 | massif_sipo
 | A_T_C | A_T_H_8 | 780,0mm | 100,0mm | 24,0mm | 0.001872 | massif_sipo
 | A_T_C | A_T_H_7 | 780,0mm | 100,0mm | 24,0mm | 0.001872 | massif_sipo
 | A_T_C | A_T_H_2 | 780,0mm | 100,0mm | 24,0mm | 0.001872 | massif_sipo
 | A_T_C | A_T_H_1 | 780,0mm | 100,0mm | 24,0mm | 0.001872 | massif_sipo
 | A_T_C | A_T_V_1 | 680,0mm | 100,0mm | 24,0mm | 0.001632 | massif_sipo
 | A_T_C | A_T_V_3 | 680,0mm | 100,0mm | 24,0mm | 0.001632 | massif_sipo
 | A_T_C | A_T_V_2 | 680,0mm | 100,0mm | 24,0mm | 0.001632 | massif_sipo
 | A_P_G_C | A_P_G_V_2 | 680,0mm | 100,0mm | 24,0mm | 0.001632 | massif_sipo
 | A_P_G_C | A_P_G_V_1 | 680,0mm | 100,0mm | 24,0mm | 0.001632 | massif_sipo
 | A_P_G_C | A_P_G_H_1 | 588,0mm | 100,0mm | 24,0mm | 0.001411 | massif_sipo
 | A_P_G_C | A_P_G_H_4 | 588,0mm | 100,0mm | 24,0mm | 0.001411 | massif_sipo
 | C_T | C_T_1 | 1660,0mm | 100,0mm | 24,0mm | 0.003984 | massif_sipo
 | C_T | C_T_2 | 1660,0mm | 100,0mm | 24,0mm | 0.003984 | massif_sipo
 | C_T | C_T_3 | 1660,0mm | 100,0mm | 24,0mm | 0.003984 | massif_sipo
 | C_T | C_T_4 | 1660,0mm | 100,0mm | 24,0mm | 0.003984 | massif_sipo
 | A_PI | A_PI_1 | 704,0mm | 85,0mm | 20,0mm | 0.001197 | massif_sipo
 | A_T_P | A_T_P_3_3 | 710,0mm | 95,0mm | 10,0mm | 0.000675 | massif_sipo
 | A_T_P | A_T_P_4_3 | 710,0mm | 95,0mm | 10,0mm | 0.000675 | massif_sipo
 | A_T_P | A_T_P_2_2 | 710,0mm | 95,0mm | 10,0mm | 0.000675 | massif_sipo
 | A_T_P | A_T_P_1_2 | 710,0mm | 95,0mm | 10,0mm | 0.000675 | massif_sipo
 | A_P_G_P | A_P_G_C_1_2 | 518,0mm | 95,0mm | 10,0mm | 0.000492 | massif_sipo
 | A_P_G_P | A_P_G_C_3 | 518,0mm | 95,0mm | 10,0mm | 0.000492 | massif_sipo
 | A_P_G_P | A_P_G_C_2_2 | 518,0mm | 90,0mm | 10,0mm | 0.000466 | massif_sipo
 | A_T_P | A_T_P_4_1 | 710,0mm | 110,0mm | 10,0mm | 0.000781 | massif_sipo
 | A_T_P | A_T_P_4_2 | 710,0mm | 110,0mm | 10,0mm | 0.000781 | massif_sipo
 | A_T_P | A_T_P_3_2 | 710,0mm | 110,0mm | 10,0mm | 0.000781 | massif_sipo
 | A_T_P | A_T_P_2_1 | 710,0mm | 110,0mm | 10,0mm | 0.000781 | massif_sipo
 | A_T_P | A_T_P_1_1 | 710,0mm | 110,0mm | 10,0mm | 0.000781 | massif_sipo
 | A_T_P | A_T_P_3_1 | 710,0mm | 110,0mm | 10,0mm | 0.000781 | massif_sipo
 | A_P_G_P | A_P_G_C_1_1 | 518,0mm | 110,0mm | 10,0mm | 0.00057 | massif_sipo
 | A_P_G_P | A_P_G_C_2_1 | 518,0mm | 100,0mm | 10,0mm | 0.000518 | massif_sipo

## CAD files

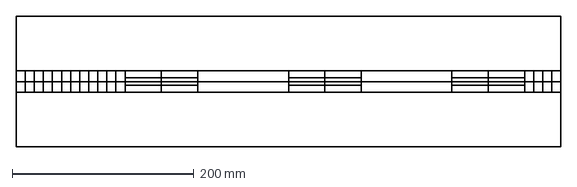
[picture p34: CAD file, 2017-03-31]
building/templates/patron_faux_tenons.dxf
600.0 x 144.0 mm

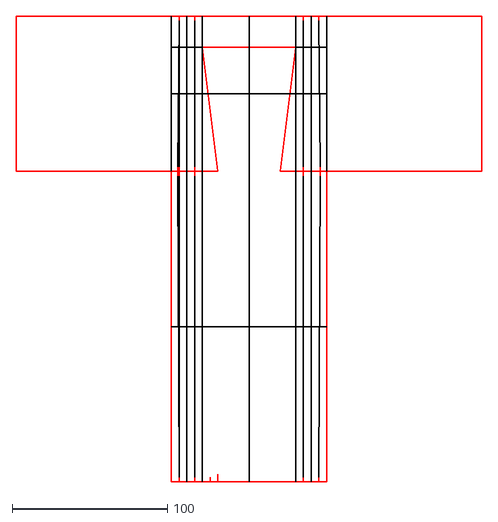
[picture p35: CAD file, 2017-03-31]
building/templates/patron_queue_aronde_socle.dxf
300.0 x 300.0

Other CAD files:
3D_model/modern_captain_bed.skp

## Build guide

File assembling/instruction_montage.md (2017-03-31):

#Construction du lit#
## concept ##
L'idée est de faire un lit démontable surélevé inspiré des meubles de bateau du 19em siècle, d'aspect moderne,
mais disposant de vastes rangements adapté à la vie dans de petite surface .

Ma conception du design est d'avoir un objet :
 * fonctionnel
 * beau
 * durable
 * sobre

L'aspect technique est particulièrement important pour un lit 
qui est un meuble utilisé plusieurs heures par jours et soumis à pas mal de contraintes.
L'aspect esthétique est aussi primordiale, car puisqu'on surélève le lit, 
on augmente beaucoup sa taille subjective, et on court le risque de créer un élément qui écrase le reste de la pièce.

La durabilité est extremement importante philosophiquement (cristallisation du travail qui doit être transmise) et 
économiquement (seul un lit qui peut être gardé longtemps permet de justifier des materiaux de luxe, une construction complexe et un travail important pour le réaliser).

La sobriété découle de mes gouts esthétique et de l'imperatif de durabilité (la sobriété limite la maintenance).
Par ailleurs pour les projets sur mesure il est courant de tomber dans le sur-design.
Je m'inspire du rasoir d'Ockham et décrète que la solution la plus simple est préférable.

## Philosophie du design##

En terme mécanique, le lit ne respect pas les règles appliquées aux materiaux idéaux,
car il faut prendre en compte les variations de dimensions du bois, ses déformations (du à la charge ou pas)
et aussi les marges d'erreur lors de la construction qui doivent être suffisante pour qu'un 
amateur puisse fabriquer le lit.
Les choix d'assemblages sont justifiés.

Je m'inspire de certains éléments du developpement logiciel pour les appliquer à la menuiserie.
 * En particulier, j'intègre la dimension de modularité pour désigner sous systeme par sous système, 
et réduire la complexité de construction et les possibles conséquences d'erreur.
 * le deuxième élément est l'utilisation de méthode de test au fur et à mesure de la construction pour vérifier les sous systèmes, voir chaque assemblage.

## plan ##
Les plans sketchup sont disponibles,
tous les assemblages n'ont pas été dessiné par confort.
On peut consulter le graphe de liaison pour un récapitulatif des assemblages entre les pièces.

Le premier élément à intégrer est la nomenclature.
Le lit est divisé en sous partie,
les numérotations se font de haut en bas ou de gauche à droite 
ou de tête de lit vers le pied de lit.

Les sous parties sont 
 * Le socle (SOC)
 * les armature (A)
 * la ceinture (C)
 * la partie sommier (LS et L)
 
## construction et choix de design##
### Préparation ###
La liste des pièces est disponible,
j'ai acheté le bois au dimension, ce qui requiert d'avoir du bois biens sec pour éviter les déformations ultèrieurs.
La première chose à faire est le transport
Ensuite il faut impérativement nommé chaque pièce, en utilisant de la craie foréstière.
Vu le nombre de pièces (plus d'une centaine), c'est fastidieux mais absolument indispensable.

### Le Socle ###
#### Design####

Pour palier au sol non parfaitement plan, pour permettre un déplacement par glissement du lit,
pour augmenter la rigidité de l'ensemble, le lit est doté d'un socle qui sert de référence et sur lequel repose tout le reste.
A la base il s'agit de 4 planches en réctangles, augmentées de planches supplémentaires sous les éléments verticaux du lit (les armatures).

Ces planches supporte le poids total du lit (250kg+ personnes + poids tiroirs + poids contenu tiroir),
le rectangle pourrait être soumis à des forces de cisaillements (un coté ), et ne doit pas trop 
glisser au sol .

Je choisi des planches de 24 mm de hêtre, avec un doublure adaptée au sol (sol normal : liège, sol très déformé : mousse de tapi de sol)
qui sert d'amortisseur accoustique et mécanique, et d'interface pour limiter les variations de planéité du sol.

##### Socle- Socle
On demande essentiellement à ces planches de maintenir leur equerrage,
la solution classique serait des tenons mortaises, 
je choisi des grandes queues d'arondes à plat en mi bois.

Les avantages sont la rigidité et la resistance,
le défaut est l'hyperstatisme très conséquent qui fait que les 4 planches éxterieur doivent être bien ajustée,
puis les autres parfaitement ajustées à leur tour.

Le plan pour un gabarit est disponible.

##### Socle-Armature
Le plan pour un gabarit est disponible.

Ces assemblages assure la totalité des liaisons entre le lit et le socle. 
La contrainte d'avoir des tiroirs potentiellement traversant empeche d'utiliser des pièces qui feraient équerre en bois.
Le socle ne pourra donc pas maintenir les armatures debout et d'equerre. 
On décompose donc le problème autrement : 
le socle empeche les armatures de bouger dans le plan XY, mais ne garantie pas leur equerrage (celui ci resulte de la boucle armature+ceinture)

Pour cela on utilise des faux tenons, assez peu ajustés dans la longeur, mais ajusté en largeur. De cette façon, les armatures peuvent se déplacer de quelques 
millimètre en translation dans leur largeur, mais sont bloqué à quelques dixième de mm en translation dans la direction perpendiculaire.

L'autre solution serait que les armatures s'encastrent dans le socle, ce qui serait beaucoup plus contraignants en terme de précision d'assemblage,
et ferais risquer l'éclatement.

#### Réalisation ####
##### Socle - Socle
queue d'aronde plates

Tracer sur les planches en rattrapant les éventuels problème de longueurs de certaines planches.
Tracer aussi la ligne centrale sur `S_GD_2 et S_GD_3 et S_TP_2`

J'ai choisi d'utiliser un gabarit pour guider la défonceuse.
découper le gabarit au laser ou à la main de façon très soigneuse.
Il faut impérativement que le gabarit de guidage soit assez épais pour être résistant (medium >5mm).

Pour l'aronde male, réduire le mi bois à la défonceuse ou scie à ruban à lame largetrès rigide.
Dégrossir l'aronde male à la scie (à ruban), puis utiliser la défonceuse guider par le gabarit pour finir la forme exacte.

Pour l'aronde femelle,
percer à mi bois la partie à enlever à la perceuse pour réduire le travail de la défonceuse.
Utiliser la défonceuse avec une fraise roulement en haut et le gabarit pour finir l'aronde femelle,
ou défoncer à main levée et finir au ciseau à bois pour des bords nettes (utiliser une chute pour être bien vertical).

Parafiner les assemblages, puis les tester/ajuster en testant d'abord `S_TP_1, S_GD_1, S_TP_3, S_GD_4`.
Personnellement j'ajuste les assemblages avec une lime fine.
C'est déconseillé, mais je n'ai pas vu de raison valable de ne pas le faire sur bois dur.

Assembler tout le socle et vérifier les dimensions.

##### Socle-Armature #####
mortaise faux tenons

Les tracés sont essentiel.
Utiliser le gabarit pour tracer,
puis utiliser la défonceuse et le guide parallèle pour creuser les mortaises dans le socle.
l'endroit de début et de fin de chaque mortaise étant fait en respectant les tracées, avec qq mm de marge.
Le positionnement des mortaises est en revanche essentielle en largeur de la planche, et doit être le plus précis possible 
(1/10 mm, attention à l'usure de la fraise qui ne fera plus nécessairement 8mm)
Attention, tous les faux tenons ne sont pas centrés, ceux sur `SOC_TP_1, SOC_GD_1` ne le sont pas.
Attention de même pour le positionnement des mortaises sur `SOC_TP_3`.

(optionnel : en profiter pour les marques de début/fin de mortaises sur les parties concernées des armatures,
en pensant bien à tenir compte des parties verticales des armatures).

### Armature ###
#### Design ####

##### Armature - Amature
##### Armature - Socle'

#### Réalisation ####
##### Socle - Socle
##### Socle-Armature #####

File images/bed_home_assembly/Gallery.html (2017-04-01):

# Gallery

Click on picture to enlarge.























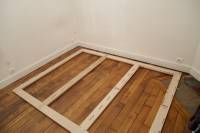
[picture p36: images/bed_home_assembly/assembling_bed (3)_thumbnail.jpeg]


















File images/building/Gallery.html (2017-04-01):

# Gallery

Click on picture to enlarge.



































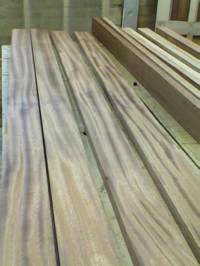
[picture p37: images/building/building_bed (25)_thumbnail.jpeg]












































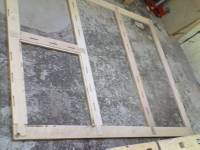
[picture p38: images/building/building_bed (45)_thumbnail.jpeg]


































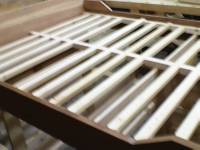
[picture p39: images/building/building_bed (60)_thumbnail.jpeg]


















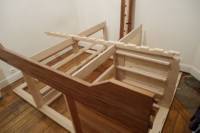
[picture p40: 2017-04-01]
images/bed_home_assembly/LQ/assembly_bde__LQ (12)_thumbnail.jpeg

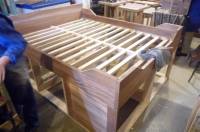
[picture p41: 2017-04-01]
images/bed_at_woodshop/assembly_at_woodshop (32)_thumbnail.jpeg

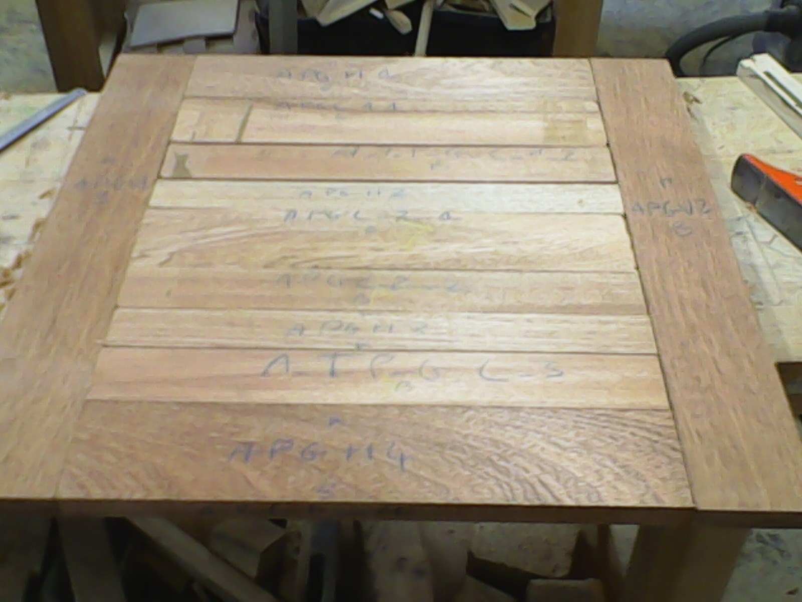
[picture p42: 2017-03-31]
images/building/building_bed (17).jpg

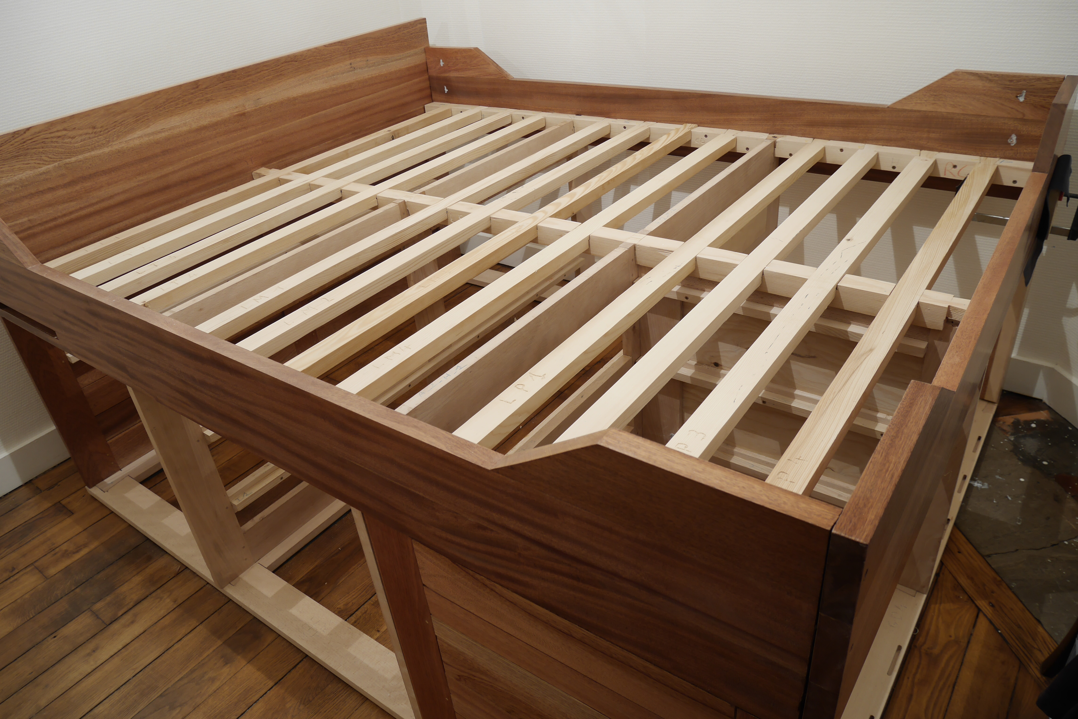
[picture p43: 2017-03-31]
images/bed_home_assembly/assembling_bed (17).JPG

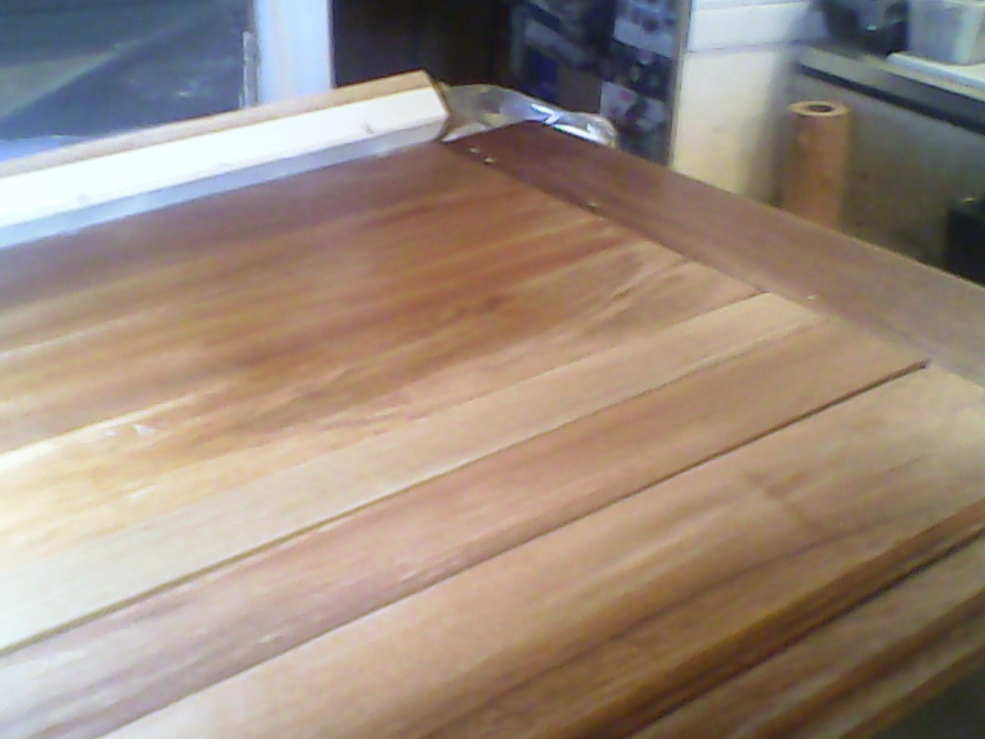
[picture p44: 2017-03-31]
images/building/building_bed (65).jpg

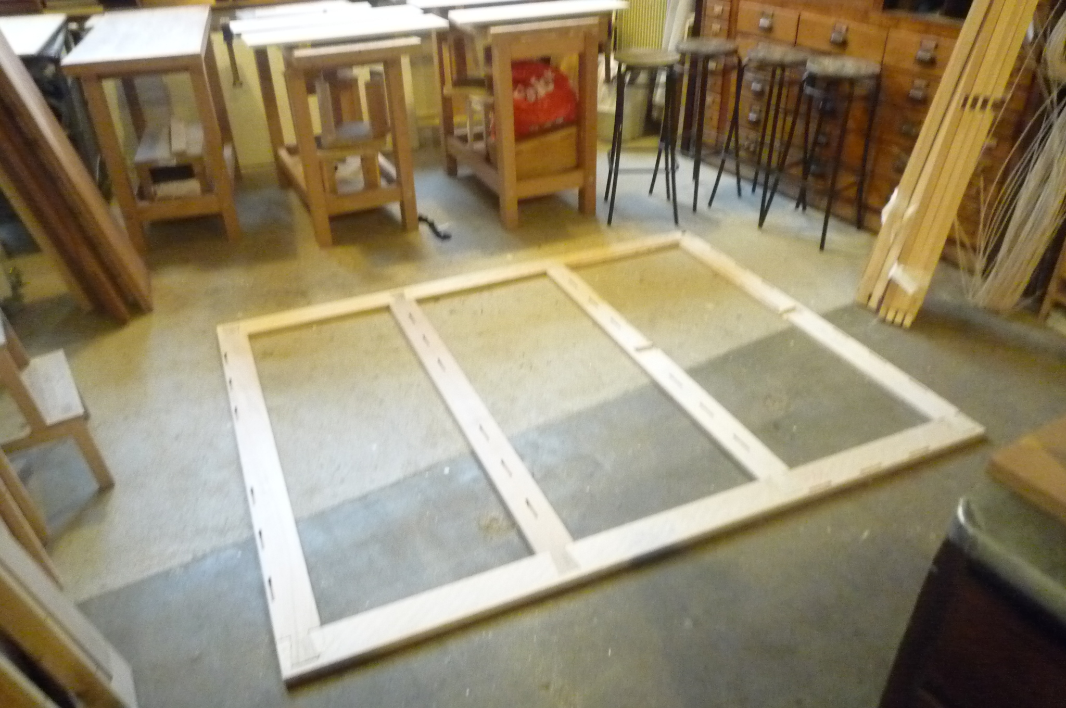
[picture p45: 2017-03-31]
images/bed_at_woodshop/assembly_at_woodshop (7).JPG

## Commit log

2017-03-31 adding open source plans and pictures
    [dim_export.ods, dim_export.xls, modern_captain_bed.skp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]
2017-04-01 adding export to collada for 3D viewer
    [modern_captain_bed.skp]
